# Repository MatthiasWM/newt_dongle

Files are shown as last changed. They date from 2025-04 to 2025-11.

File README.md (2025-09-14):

# User Manual
## Newton MessagePad MP2x00 and eMate 300 USB Dongle

The NewtCOM dongle connects the Apple MessagePad MP2x00 and the eMate to a PC
or Mac over USB-C.

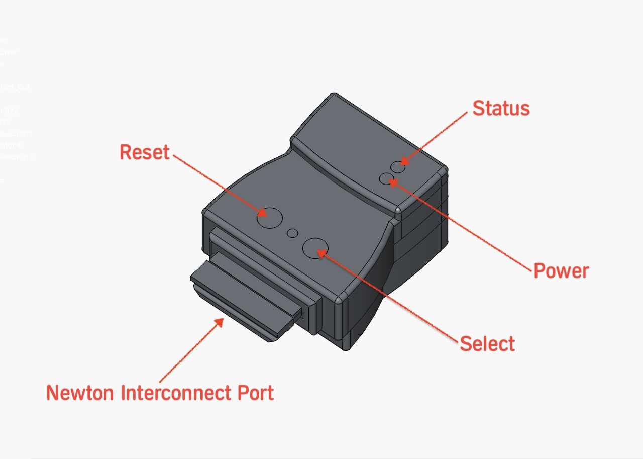
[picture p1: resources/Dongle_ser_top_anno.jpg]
Dongle Front Top View


The dongle plugs into the rear of the MessagePad or the left side of the eMate.
On the top are two recessed buttons, one for resetting the device, and a second
button to select additional functions.

Two LEDs indicate the current state. The Power LED lights up red when the 
Dongle is either connected to a USB-C port, or when plugged into the Newton
*and* a serial connection is requested.

The Status LED shows the communication status of the Dongle.

 - yellow: idle, waiting for a connection
 - green: an application on the PC or Mac has connected to the Dongle over USB-C
 - blue: the Newton is connected to the Dongle's built-in NCU
 - flashing light blue: the Dongle is reading from the SD Card

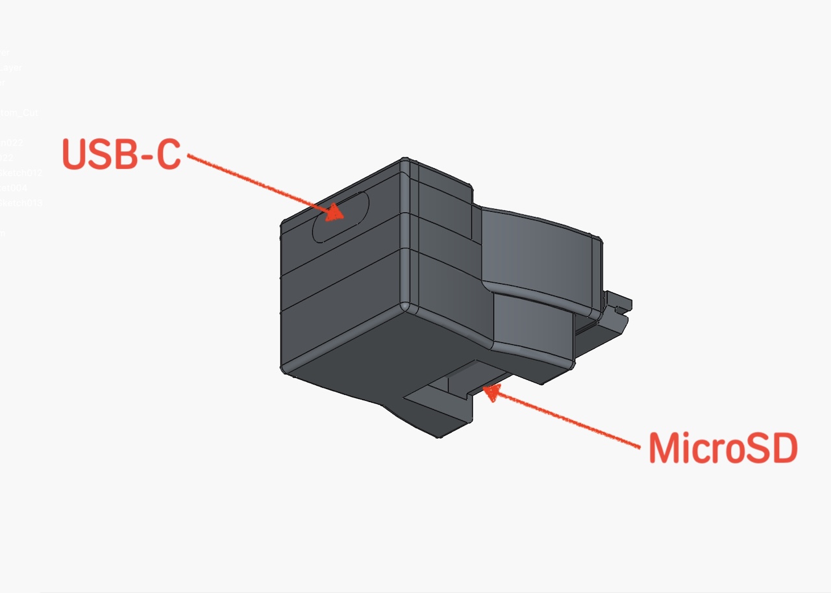
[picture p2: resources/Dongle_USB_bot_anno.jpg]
Dongle Back Bottom View


### USB-C Port for Data and Power

The USB-C port is located on the back of the dongle. When connected to a PC, it 
typically supplies enough power to operate the Newton with two standard PCMCIA 
cards installed.

However, this may not be sufficient to power WiFi cards or charge the battery pack.

### MicroSD Card Slot

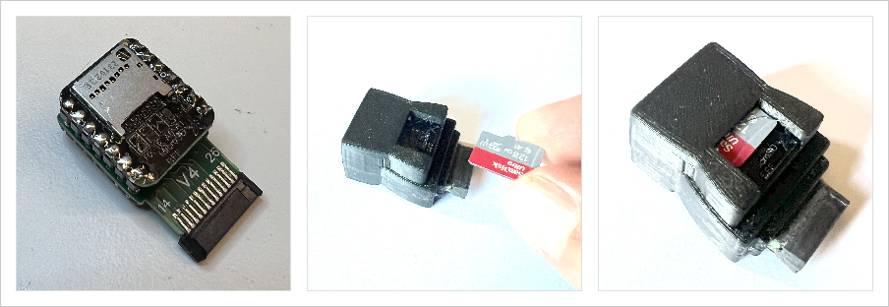
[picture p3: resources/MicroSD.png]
Micro SD Card Slot


The bottom of the dongle includes a slot for a MicroSD card. To insert or 
remove the card, you must first unplug the dongle from the MessagePad.

When inserting the MicroSD card, make sure the metal contacts face the 
dongle — this is the "up" direction when the dongle is connected to the Newton.

The MicroSD card must be formatted with the FAT32 file system.

> [!TIP]
> The shape of the dongle ensures that it can't be plugged in up-side down.
> Make sure that the interconnect plug is pushed in all the way in for a secure
> connection.

## Serial Mode

The dongle works as a serial connection between the Newton and the PC or Mac,
running any of the common Newton synchronization tools. It has been tested with
NCU, NCX, unixnpi, and NTK. 

Also the low level debugging tool Hammer works fine using the BasiliskII emulator.
Note that older versions of Baslilisk do not support serial port emulation.
These versions should: 
[MacOS](http://messagepad.org/Downloads/Einstein/MacOS/BasiliskII.MacOS,E.2.zip),
[Windows](http://messagepad.org/Downloads/Einstein/MSWindows/BasiliskII.Windows.E.4.zip),
[Linux Ubuntu LTS](https://github.com/pguyot/Einstein/releases/download/v2022.4.17/Einstein_linux_x64_fltk_v2022.4.17.zip).

### USB-C Serial Connection

When the dongle is connected to a modern computer via USB-C, it appears 
as a serial port.

 - On macOS and Linux, it will show up as something like 
   `/dev/cu.usbmodem83201` (the exact number may vary).
 - On Windows, look for a COM port such as `\\.\COM5` or similar in your 
   device manager.

###  Transfer Speed

The communication speed is controlled by the computer. For example, NCX can be 
set to use a faster transfer rate like 115,200 bps instead of the default 
38,400 bps. If you choose a higher speed, be sure the "Serial 11200" Dock 
package is installed on the Newton.

The dongle automatically adjusts to the speed set by the computer. If no 
computer is connected, it defaults to 38,400 bps.

### Flow Control

The NewtCOM dongle uses Newton-style hardware handshaking and includes 
internal throttling to ensure smooth, reliable data transfer.

> [!TIP]
> If transfer of large files still occasionally hangs during transfer, the 
> throttling parameters can be adapted using Hayes commands (see below). 
> The default values are an educated guess. Please let me know if you find
> better values that work for every configuration.

## Dock mode (Firmware v0.6 and later)

Firmware version 0.6 introduces basic support for the Newton Docking protocol. 
This allows the dongle to emulate a minimal NCU-like app, enabling package 
installation directly from a MicroSD card—no computer required.

### Preparing the MicroSD Card

 - Copy your .pkg files to the MicroSD card.
 - You can organize them into folders; subfolders are fully supported.
 - For best performance, limit each directory to no more than 50 files or folders.
 - The card must be formatted as FAT32.

### Using Dock Mode

 - Insert the MicroSD card into the slot on the bottom of the dongle.
 - Connect the dongle to your Newton. (It can also be connected to a computer 
   via USB, but no app like NCX or NCU should be actively using the port.)
 - The LED on the dongle should light up yellow, indicating it's ready.
 - On your Newton, open the Dock app.
 - Select `Serial` as the connection method, effectively setting the speed to 38,400 bps.
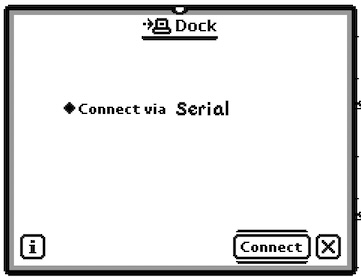
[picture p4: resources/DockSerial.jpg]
Dock Serial
   
 - Tap Connect. After 4–5 seconds, the LED will change to blue, and a Docking 
   window should appear with an option to browse the SD card.
 - Tap the icon to view a list of files and folders.
 - Select a package, tap Install, and the Newton will download and install 
   it directly from the card.

> [!TIP]
> If no SD Card is in the slot, or NewtCOM can't read the SD Card for some
> other reason, the name of the card will be "Error". Try to reset the dongle.
> If that does not help, remove power from the dongle and start over. If that
> still doesn't help, try another SD Card.

## Updating Firmware

All official releases of the firmware will be published [here](https://github.com/MatthiasWM/newt_dongle/releases).

To update the firmware, download the file ending in `.uf2` to your PC. 

To put the dongle into firmware mode:

- disconnect the dongle from the Newton
- connect the dongle to your PC or Mac via USB-C 
- get two pointy tools to press the recessed buttons
- press and hold the RESET button
- press and hold the SELECT button
- release the RESET button
- release the SELECT button
- the dongle switches into firmware mode and shows up as a new USB drive `RPI-RP2` on your desktop
- now simply drag and drop the `.uf2` file onto the USB drive
- the USB drive will disappear and the dongle will reboot into the new firmware

## Hayes Command Mode

The NewtCOM dongle can be put into Hayes command mode on both the serial port 
and the USB port. To do this, you will need a terminal program. On the Newton
side, this is commonly `PT100`. The Newton serial port speed defaults to 38'400bps. 

There are many VT100 or simpler terminal programs for PCs 
and Macs. The dongle should be listed as `/dev/usbmodemXXX` where XXX is 
some random number. If connected via USB-C, the dongle will adapt to the serial port
speed set by the PC.

To get into Hayes mode, don't send any data for at least one second. 
Then, again within a second, type `+++` (three plus characters - on PT100, you can
create a macro for that - don't press Return). After yet another second 
without, if no keys are pressed, the dongle will reply with `OK`. 

You are now in Hayes mode. To get back online, type `ATO` (the letter "O", 
like Online). The dongle replies `CONNECT` and leaves Hayes mode.

There are few Hayes commands at this point, but there will be more:

- `ATO` : go back online
- `ATIn` : get information about the firmware and the firmware version number, n can be 0, 1, or 2.
- `AT&W` : write current settings to Flash memory
- `ATS12=n` : set the Escape Code guard time in n times 1/50th of a second (defaults to 50)
- `ATS300=n` : set the MNP throttle delay to n microseconds (defaults to 400)
- `ATS301=n` : set an additional delay in number of characters (defaults to 8)
- `AT[GL` : get the SD Card label

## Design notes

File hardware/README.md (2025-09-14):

# Hardware supported by NewtCOM firmware

As of May 2025, `NewtCOM` supports  the RP2040 base NewtCOM Dongle. 

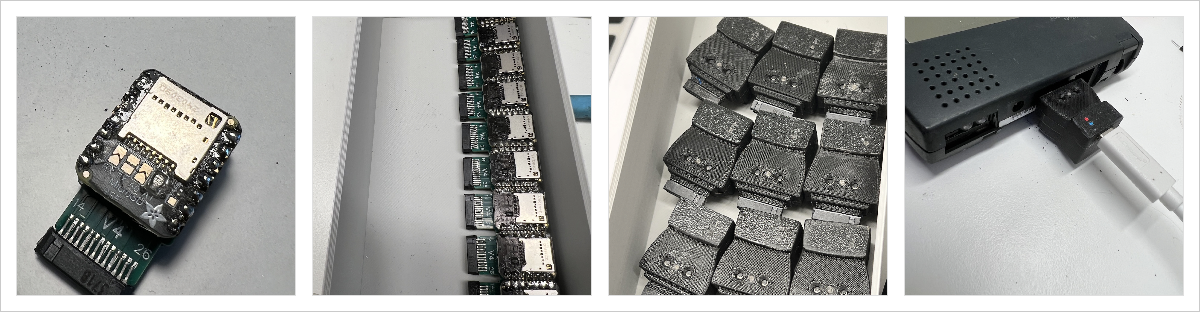
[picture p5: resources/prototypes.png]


## The NewtCOM Dongle

The design of the dongle is OpenSource and I encourage anyone with sufficient 
soldering skills to build their own dongle. There is a base dongle that 
converts the Serial Port signals on the Interconnect port to USB-C. Optionally,
the dongle can convert the 5V form the USB-C to 7V to run the Newton. There
is also an option for a MicroSD card slot for installing software without
needing a PC, and eventually for making backups and restoring the content of 
the MessagePad or eMate.

So here is how you build one:

Parts:

- Interconnect Port connector 
  - V4: Molex 71439-0964, Mouser: 538-71439-0964
  - V5: Molex 71439-1464, Mouser: [538-71439-1464](https://www.mouser.de/ProductDetail/Molex/71439-1464)
- RS422 circuit board ([oshwlab.com](https://oshwlab.com/matthiasm/interconnecttousb_copy_copy_copy))
- XIAO RP2040 circuit board, [Seeed Studio](https://wiki.seeedstudio.com/XIAO-RP2040/)
- optional: Pololu 4943 DC-DC power converter, [Pololu](https://www.pololu.com/product/4943)
- optional: Adafruit 5683 microSD Card BFF, [Adafruit](https://www.adafruit.com/product/5683)
- various pin headers that usually come with the boards above
- 3d printed case (TODO: insert link)

Tools:

- Soldering iron and solder wire
- Hot air gun and SMD solder paste
- multimeter
- small needle nose pliers
- small hacksaw
- electronics wire cutter
- 3d printed jigs

## Step by step

### Ordering the RS422 circuit board

The PCB design can be dowloaded for [oshwlab.com](https://oshwlab.com/matthiasm/interconnecttousb_copy_copy_copy). The PCB can be manufactured based on these
files. Some services (I used JLCPCB) offer the complete assembly for a low rate
if you can't solder SMDs, especially the tiny diode.

The PCB should be 1.6mm thick.

### Preparing the Interconnect Port connector

#### IEEE 1386

The original Interconnect Port connector is no longer manufactured. We are 
helping ourselves with a heavily modified IEEE 1386 connector. One Molex 
71439-0964 (Mouser 538-71439-0964) yields two Newton connectors.

V5 and up uses 71439-1464.

Note that after cutting these to pieces, they wil not be as strong as the 
originals, and I have not found a way to cut the shielding. For normal use, this
should not matter.

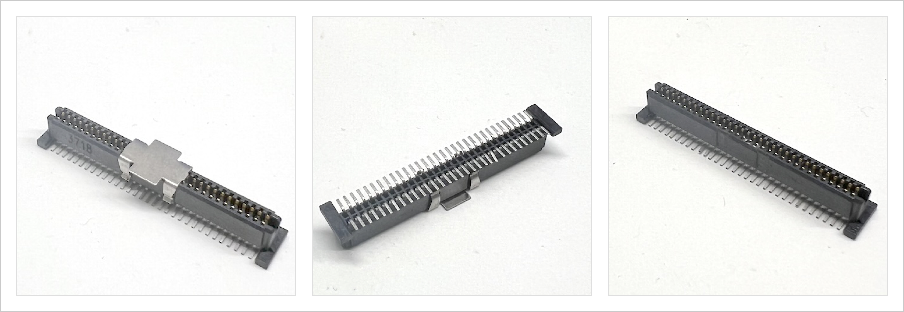
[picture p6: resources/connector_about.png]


This is the standard Molex IEEE 1386 connector. Remove the metal cap (that's
only needed for pick'n'place machines) and make sure the pins on the bottom are not bent out of shape.

#### Jigs

After cutting and filing a few connectors by hand, I decided to build jigs that make this work really easy. The STL files to print the jigs are [here](/3d-parts/jigs/). I printed the jigs with a 0.4mm nozzle at 0.2mm layer height.

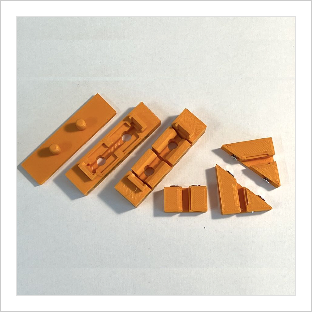
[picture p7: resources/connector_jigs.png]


#### Prebend

We need to remove 12 pins from the connector. Our (Prebend Jig)[/3d-parts/jigs/Connector_Prebend_Jig.stl] bends those pins that must be removed. Just push the connector all the way into the opening. Use the ejector to remove the connector again.

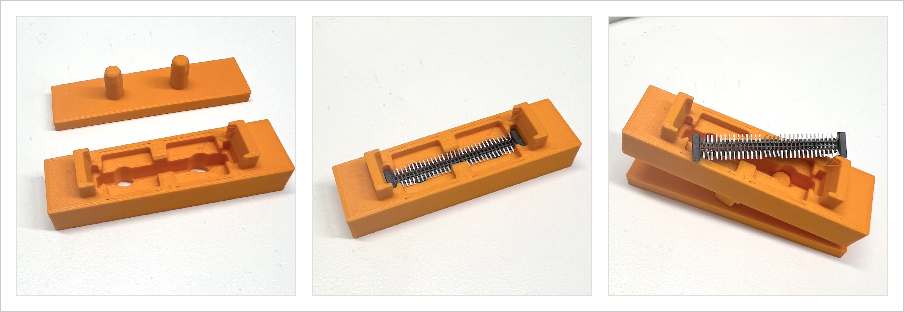
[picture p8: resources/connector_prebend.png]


The jig will bend the pins that need to be remove up slightly. Take your needle nose pliers out and remove the first pin, the four center pins, and the last pin on each side, so 12 pins alltogether. We should have two groups
of pins now on either side with 13 pins per row, or 26 pins per group.

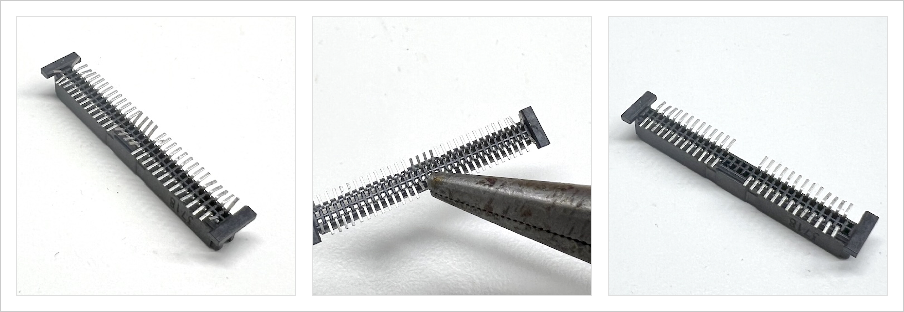
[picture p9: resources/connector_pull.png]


#### Cut

Use the cutting jig and the small hacksaw to cut the original connector into two new connectors. Three cuts are needed.

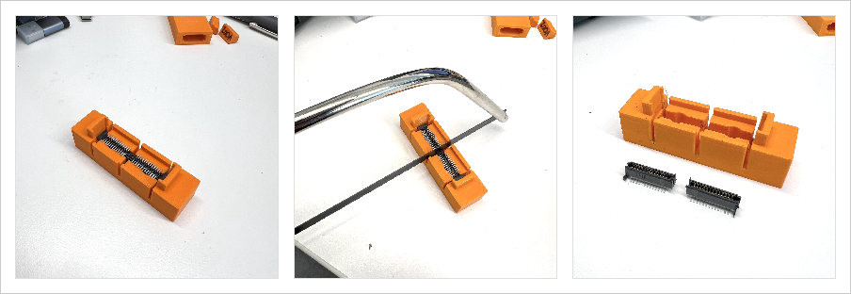
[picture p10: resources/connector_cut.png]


#### File Sides

The Interconnect Port connector must be 15.6mm wide. File the plastic off of our part evenly on both ends until you reach the desired width. The jig can help, but the 3mm bolts must be adjusted to the correct distance.

*Don't* bend any pins.

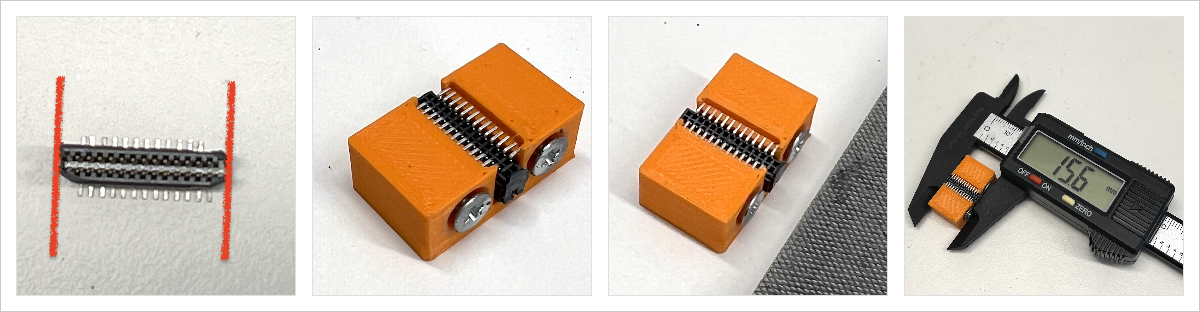
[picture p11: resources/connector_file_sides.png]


#### Final Bend

This step is the most difficult one. The connectors tend to break if done 
incorrectly. So I developed a jig that makes this step much easier. 

Insert the plug into the top of the bender. Insert the plunger between the pin 
rows and push it all the way down.

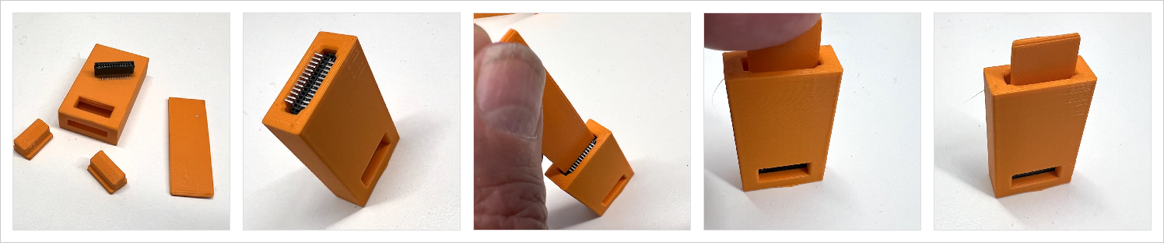
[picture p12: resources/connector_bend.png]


Keep the plunger between the contacts and grab the two pistons. Without 
lifting the jig, push the two pistons into the side openings (the slant 
faces down). Remove the plug. The pins are now bent away from the plug without 
damaging the plug's case. 

With the pins bent to back, we can now file the indexing corners.

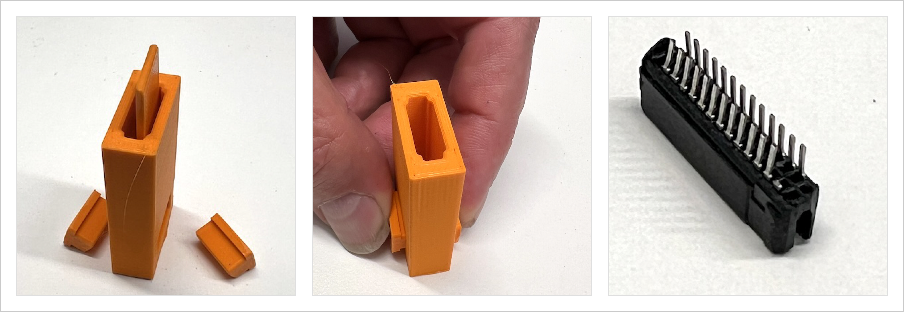
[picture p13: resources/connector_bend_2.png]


#### File Corners

To ensure that the connector is not inserted upside down, the corners on the 
bottom must be filed to 45 degrees. Again, the two jigs for left and right 
should help. Make sure that you file the corners on the *same* side.

*Don't* bend any pins.

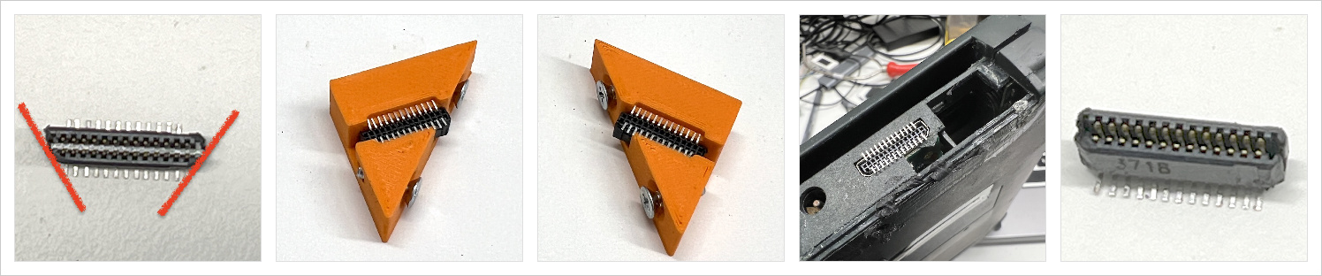
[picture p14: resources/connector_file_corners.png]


The last image show a test fit in a MessagePad. The connector should fit snug, 
but not get stuck. Did I mention to not bend any pins? Well, if you did, and 
you did bend them back too many times, they probably broke off by now. Throw 
away the connector and try again.. 

### Soldering the connector

Position the connector correctly on the RS422 board. The first two images show the *bottom* of the board. Make sure that the 45 degree corners are on the *bottom* side of the PCB. The third image show the *top* of the PCB with no parts on it. The connector must have the 90 degree corners on the top!

Look at the PCB from the side: the connector must be straight with the PCB, not pointing up or down.

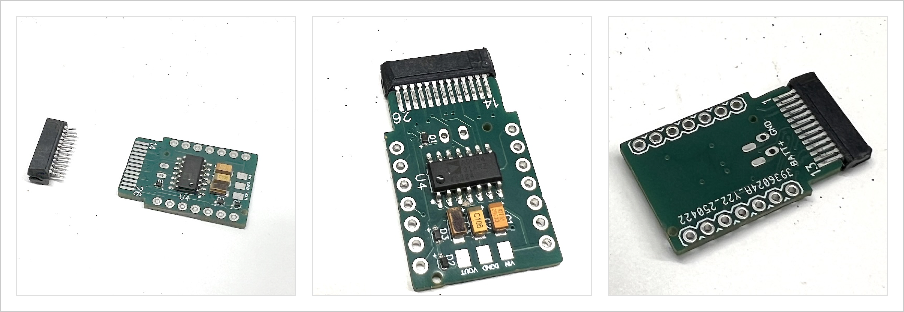
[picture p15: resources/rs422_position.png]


Soldering is easy with some fresh solder paste and a hot air gun. Just add a small bead and heat one side of the connector until the solder balls disappear and teh solder is shiny. The pin distance it 1mm. It's also relatively easy to solder this with a regular soldering iron, flux, and a fine tip.

Did you solder the connector on the right way? Did you make sure the 45 degree corners are on the side where the parts are?

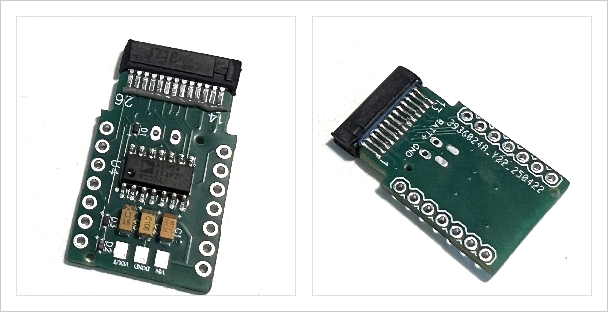
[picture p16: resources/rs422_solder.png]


Let's do a mechanical check first. Here we see the RS422 board plugged into my MessagePad (it's a very roughly used MP, sorry for the scratches). The left photo show the top view, the right photo is taken from the bottom.

If you are unsure about your soldering, use a multimeter to check for shorts between pins.  Pin 15 and 16 are connected and will show a short circuot correctly. The remaining neighbors should show a high resistance.

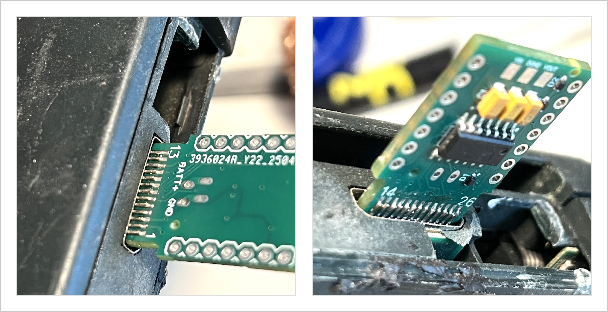
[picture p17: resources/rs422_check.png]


### Adding the DC-DC converter

The DC/DC converter takes power from the USB-C port, raises the voltage to 7.5V,
and then powers the Newton through two diodes and a filter. 

In the following pictures, I soldered the CPU board first, but it's better to 
add the DC/DC module first, so here we go:

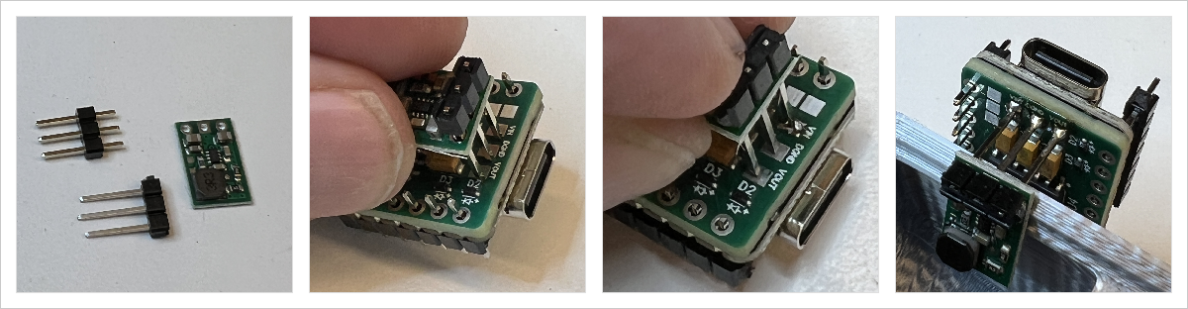
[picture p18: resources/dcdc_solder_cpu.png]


Prepare a three-pin pin header by pushing the plastic all the way up.

Put the DC/DC inverter module on the pin header. This will help keeping the
pins aligned later.

Put a first solder blob on the PCB and fix the first pin. 

When everything is aligned well, solder the other two pins onto the PCB.

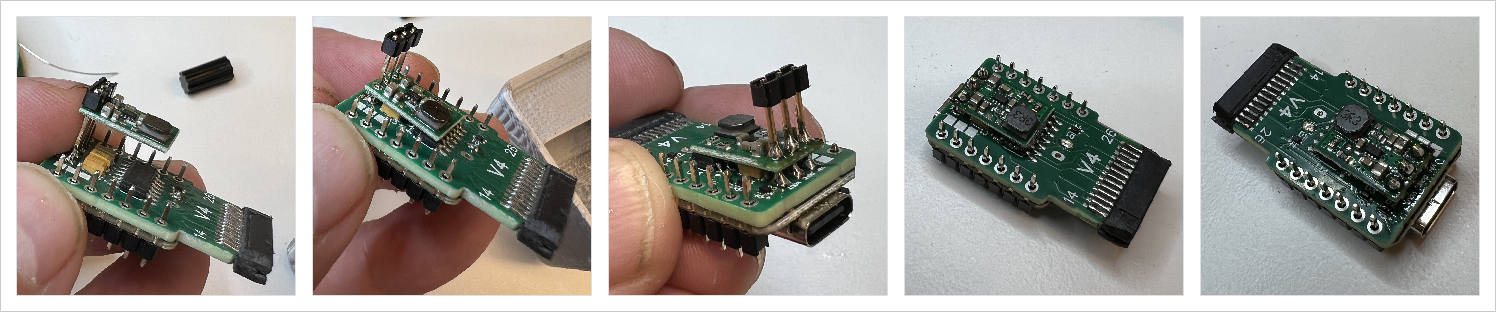
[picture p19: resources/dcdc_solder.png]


Slide the DC/DC board down and attach it to the capacitors below with a bit
of glue. This will take load off of the power pads.

Solder the three pins to the module, the remove the plastic - be careful to
hold the DC/DC module when pulling, so you don't rip the pads form the 
RS422 PCB! Finally, but the pins, and the DC/DC module will fit nicely between
the RS422 and the MicroSD board.
 
### Soldering the RS422 board to the RP2040 board

Next we will solder the CPU board to the RS422 board. Note that in the description,
I soldered the DC/DC board first, which is preferred. The photos still show
the old method. 

For now, there is only one single pad that can be soldered. The remaining pins 
will be soldered later. If connected correctly, the Newton Batt+ pin will power 
VIN on the dongle if there is no PC connected. 

From now on, the connected boards must be 
handled very carefully, or the 5V pad will delaminate.

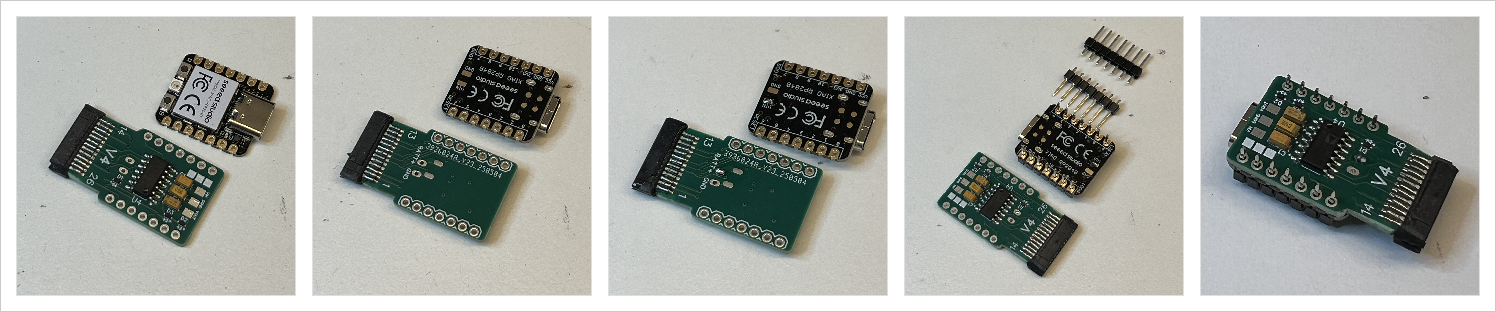
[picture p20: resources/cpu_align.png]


Prepare the CPU board by adding a little solder blob on the `VIN` pin. Put another
small blob on the underside of the RS422 board on the `BATT+` pin. 

Align the boards back to back using the pin header.

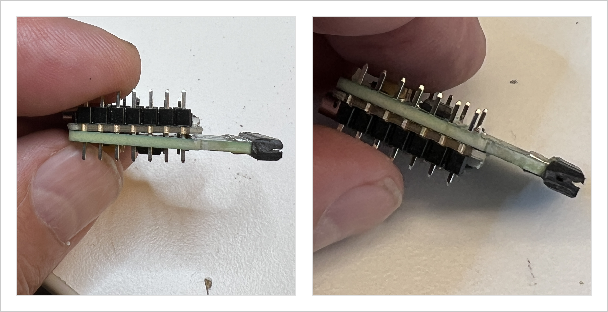
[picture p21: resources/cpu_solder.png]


There is a gap visible from the sides where both solder ball touch, but have
not melted together yet. Place the dongle firmly on the table with the CPU
board at the bottom and the RS244 board at the top. Hold the soldering tip 
to the `BATT+` through-hole, and after a second or so, both solder blobs will 
melt, joining the boards permanently. 

The gap is no longer there, and both boards stick together. 

### Adding the MicroSD board

Prepare the MicroSD board for the dongle by reconfiguring the solder pads. 

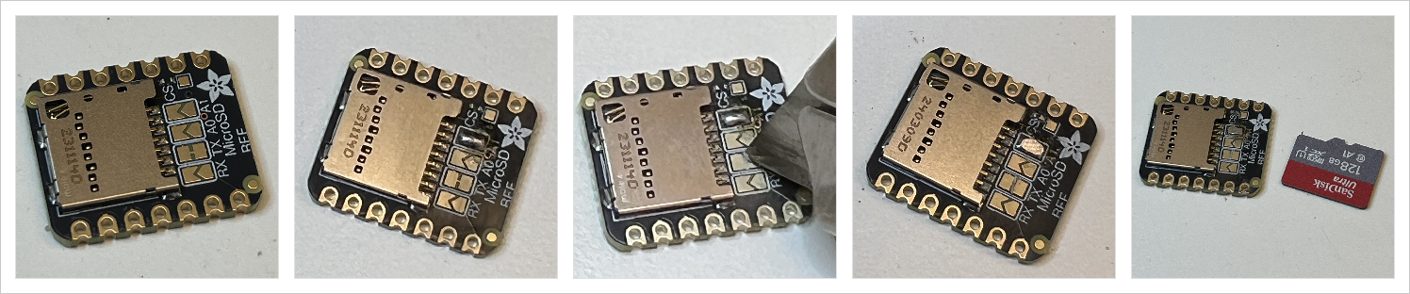
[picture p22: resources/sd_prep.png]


The SD Card module is preconfigured to select the card using the `TX` pin. We will
need the `TX` pin to send serial data to the Newton, so instead we use `A1`.

Put a solder blob on the `A1` pads so that both sides connect. File the resulting
blob down enough, so the SD Card can slide over it. Don't accidentally file the 
contacts on the sides though.

Cut the small wire between the pads of the `TX` pin with a knife. Make sure that 
there is a wide enough gap. 

It's a convinient time no to use black marker to make the color match
the dongle case.  

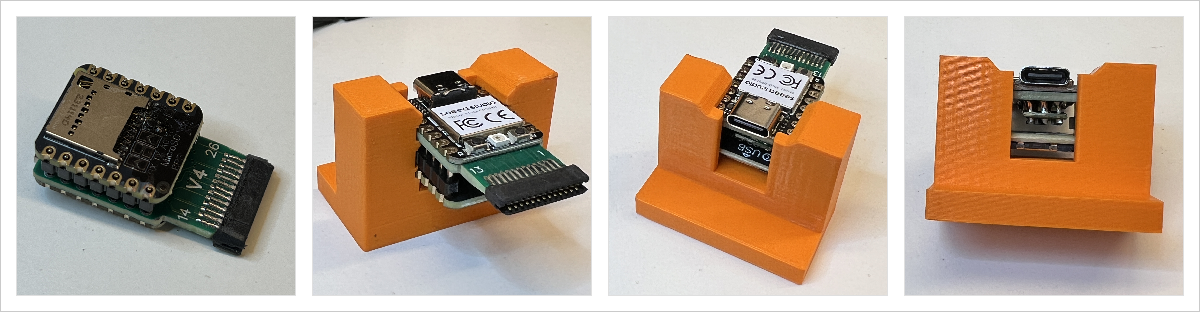
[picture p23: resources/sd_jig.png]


Without putting any stress on the CPU/RS422 sandwich, flip the header pins
in the final direction.

Add the MicroSD module to our package. Make sure that the board is oriented
in the correct way. After all the work to get here, you really don;t want to
find out that the SD Card points the wrong way when zou put everything in
the case. Ask me how I know... .

Get the assembly jig. It will make sure that the PCBs hav the right distance 
and will fit into the case later. Push the PCBs all the way to the front.
Lift the headers so the plastic fits into the gap. The tips of the pins will be 
flush or barely show, but should not be retracted, or the soldering connection will not work. 

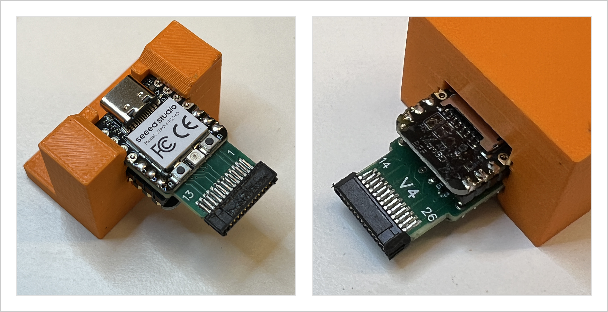
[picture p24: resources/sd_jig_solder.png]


Is the MicroSD module oriented correctly?

While the module is still in the jig, solder the six visible pins on the top
and of the bottom of the module. The PCBs are now permanently aligned. Remove
the module from the jig..

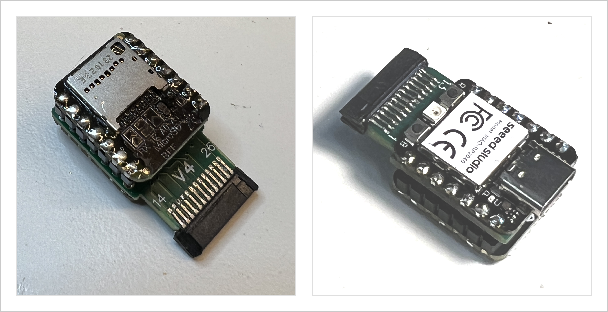
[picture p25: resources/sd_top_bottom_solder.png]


Solder the remaining pins on the top and bottom of the module. Look again.
Didi you really solder *all* of them?

* Pictures missing *

Note that the sandwiched CPU/RS422 boards don;t always connect all the way 
through. Use the angled jigs to solder the pinheaders from the RS422 side of 
the module as well.

### Flashing the Firmware

TODO: write me!
- USB Drive mode
- drag and drop

### Testing the dongle

TODO: write me!
- test power from interconnect port
- test power from USB-C
- test power to Newton
- Hayes mode, AT commands
- practical tests: NCX, Basilisk and NCU
- practical test SD Card

### Putting everything in a case

TODO: write me!
- choose a case
- print the case
- glue

### Adding the light pipes

The CPU module has three LEDs that are hard to see when the boards are 
in the case. This is easily fixable by adding light pipes, 1.5mm fibers that
illuminate the end points (there are others available that illuminate the 
circumference - don't use those).

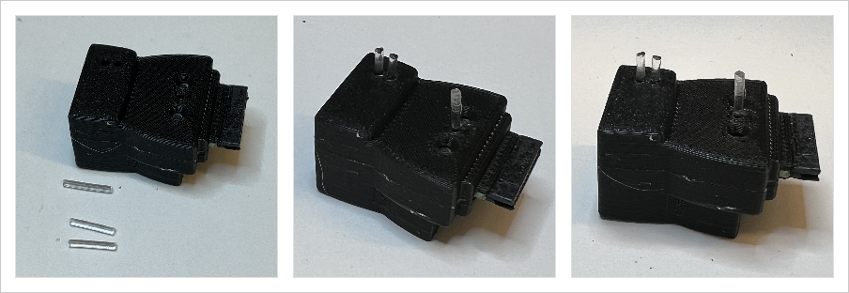
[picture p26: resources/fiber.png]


Use a drill to expand the holes of the 3d printed case to 1.5mm. Cut 
10mm pieces of fiber from the roll. Add some liquid plastic glue and push 
the three pieces int the holes. The State and Power light holes are a few
mm deep, but the front RGB LED hole is quite shallow, but since that LED
is hidden by the MP2x00 lid, it's of no use anyway.

Wait a few minutes for the glue to set, then cut the fibers with a side cutter.
There is no need to file to ends of the fiber. It;s a status LED< not an 
internet backbone connection between continents.

### Done

So, that's it from my side. You should have a nice and working dongle now.
Enjoy the Newton!

Matthias

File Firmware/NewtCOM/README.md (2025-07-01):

```
// SPDX-License-Identifier: MIT
// Copyright (c) 2025 Matthias Melcher, robowerk.de
```

# NewtCOM Dongle configuration

This is the build configuration for running the NewtCOM firmware on a 
NewtCOM Dongle with an RP2040 CPU. The firmware installes to Flash memory.

Parallel to this configuration is the PiPico setup for compiling the 
same firmware for the PiPico developer board.

## My TODO List for NewtCOM Dongle

see: [../PiPico/README.txt](../PiPico/README.txt)

Also:
 - [ ] User Documentation, reference to the resources that we use

 ## Hardware

 The pack is built with 10.5mm long pin headers, giving a top-bottom distance
 of 9.1 to 9.5mm. The overall hight is 12.5mm without USB and 13.9mm with USB
 connector. 
 
 Tip of the plug to front edge of PCBs is 10.4mm. Length over all is 31mm and
 32.5mm including the USB port.

 Width is 17.8mm. 

 The original dongle is 21.4 to 24.7mm wide, 20mm tall, and 39.4mm long 
 with Interconnect and 32,4mm without.

## Staus Report

The dongle can pipe data from the serial port to the USB port and back reliably at 115200. Various test were done with NCX and BasiliskII and 
Inspector.

The Dock protocol is implemented well enough so the Newton can establish
a connection to an emulated NCU, browse files and directories on the 
SDCard, and download and install them.

## GitHub

Task to build PiPico stuff on GitHub:

https://github.com/raspberrypi/pico-examples/blob/master/.github/workflows/macOS.yml

To drop **7.5V to \~7.2V** using two **series diodes**, you're doing a very common trick — using the **forward voltage drop** of the diodes (\~0.3V total) to bring the voltage into spec. Let’s walk through the choices and protection details.

---

### 🔧 Diode Selection

Since you're passing **up to 1A** of current, you need:

* A diode with **low forward voltage** (typically 0.2–0.4V).
* A diode that can handle **at least 1A continuous current**.
* A **common SMD package** for ease of assembly.

#### ✅ Recommended SMD Diodes

| Diode | Type | Package | Vf @ 1A | Max I | Notes |
| --- | --- | --- | --- | --- | --- |
| **SS14** | Schottky | SMA | \~0.4V | 1A (Avg) / 30A (surge) | Very common, cheap, ideal for power rails |
| **SS34** | Schottky | DO-214AB (SMA/SMB) | \~0.4V | 3A | More margin, same voltage drop |
| **MBRS130L** | Schottky | SMB | \~0.3V | 1A | Lower Vf than SS14, also common |
| **BAT54C** | Dual Schottky | SOT-23 | \~0.3V @ lower current | 200mA per diode | Too small for 1A total |

For your case:
👉 **Use two SS14s or MBRS130Ls in series**.
They’re widely available, cheap, and reliable.

---

### ⚠️ Do You Need a Fuse?

Yes, **some form of protection is wise**. DC-DC converters can fail shorted or supply too much current in a fault scenario. You want to prevent overheating or damage.

#### 🔌 Options for Electronic "Fusing":

1. **Resettable Polyfuse (PTC)**

   * Simple, self-resetting.
   * Choose one rated for **1.1–1.5A hold**.
   * Example: **MF-MSMF110** (1.1A hold, 2.2A trip).
   * SMD versions available.

2. **SMD Fuse (non-resettable)**

   * More compact and predictable.
   * Choose \~1.5A fuse to protect the 1A line.
   * Littelfuse 045101.5MRL (1206, 1.5A).

3. **Electronic Fuse IC**

   * Active current limiter (e.g., TPS25940 or similar).
   * Overkill unless you're designing for high reliability.

For most DIY or low-volume boards:
👉 **A polyfuse + TVS diode** offers good balance between protection and simplicity.

---

### 🛡️ Bonus: Add a TVS Diode for Transients

Put a **TVS diode** on the 7.2V output to clamp voltage spikes.

* For 7.2V nominal, use something like **SMBJ8.0A** (clamps at \~13V, starts at 8.9V).
* Pick one based on how sensitive your load is.

---

### ✅ Summary

* **Use 2x SS14 or MBRS130L diodes in series** to drop 0.3V.
* **Add a resettable fuse** (1.1–1.5A) or SMD fuse on the 7.5V or 7.2V line.
* **Optional but recommended:** TVS diode to protect from spikes.

Let me know what your load is — I can help tune the exact diode and protection setup.

Thanks — the Apple **Newton** is indeed **very sensitive to overvoltage**, especially on the external power input, as it was designed around linear regulators and NiCd/NiMH charging circuits. Given that:

---

### 🚨 Key Constraints

* **Never exceed 7.3V** (absolute max).
* Nominal target: **7.2V ± 0.1V**.
* Current draw: typically **<100mA**, but **may spike to 1A** when charging.
* Load is **delicate**, so reliability and protection matter more than just basic functionality.

---

### ✅ Best Diode Setup

To drop 7.5V to \~7.2V:

#### Recommended diode:

* **MBRS130L (SMB)** or **1N5819-SMD**

  * Forward drop: \~0.35–0.4V at 1A, less at lower current.
  * Current rating: 1A continuous.
  * Soft turn-on, minimal overshoot.

These will each drop around **0.2–0.3V at 100mA**, or **0.35–0.4V at 1A**. Two in series should bring 7.5V down to \~7.2V or slightly below under load — **perfect** for your case.

✅ Use: **2x MBRS130L diodes in series** in the main power path.

---

### 🔐 Protection: You Absolutely Need a Fuse and Clamp

Overvoltage = instant damage to the Newton. You want **two layers of defense**:

#### 1. **Fuse or Polyfuse**

* Use a **fast-acting SMD fuse**, like:

  * **Littelfuse 0451.125MRL** – 125mA
  * **0452.500MRL** – 500mA for some charging margin
* Or a **polyfuse**, like:

  * **MF-MSMF050-2**: 0.5A hold, \~1A trip
  * **MF-MSMF075-2**: 0.75A hold, \~1.5A trip

A polyfuse is slower but self-resetting — more forgiving.

#### 2. **TVS Diode (Clamp)**

Place a **TVS diode across the Newton’s supply input**, just before it connects to the device:

* Use **SMBJ7.0A** or **SMBJ6.5A**:

  * Breakdown: \~7.0V
  * Clamps: \~11.3V (SMBJ7.0A) or \~10.5V (SMBJ6.5A)
  * Both will prevent a >7.5V surge from reaching the Newton.

> **Note:** A Zener diode is *not fast enough* for this. Use a **TVS (transient voltage suppressor)**.

---

### 🧱 Suggested Power Path Summary

```text
[USB-C 5V] ─> [Boost Converter to 7.5V] ─> [Fuse or Polyfuse]
                                               │
                                ┌──────────────┘
                          [2x Schottky Diodes (SS14 or MBRS130L)]
                                               │
                                       [TVS Diode to GND]
                                               │
                                          [Newton Input]
```

---

### ⚙️ Extra Tips

* Test under load with multimeter: the forward drop **will vary** from \~0.25V (100mA) to \~0.4V (1A).
* Make sure the **boost converter is well filtered** — Newtons are also sensitive to ripple.
* You might consider a **low-dropout linear regulator** (e.g., **MIC29300-7.5**), but diodes are easier and smaller for this use case.

---

Would you like me to suggest exact part numbers and footprints for your PCB?

Perfect — here’s a clean, **low-part-count and safe design** for powering the Apple Newton from a USB-C supply, with **all the exact SMD part numbers** and footprints you can drop into your PCB layout.

---

## 🧩 Final BOM & Footprints

### 1. **DC-DC Boost Converter (5V to 7.5V)**

* You already have this — just ensure it’s:

  * Capable of stable 7.5V out @ 1–1.5A.
  * Has low ripple (<50mV) and soft start.

---

### 2. **Fuse / Polyfuse**

#### Option A: *Resettable Polyfuse* (recommended for gentle protection)

* **Part:** [Littelfuse MF-MSMF050-2](https://www.littelfuse.com/products/resettable-ptcs/surface-mount/mf-msmf-series/mf-msmf050-2.aspx)
* **Rating:** 0.5A hold / 1A trip
* **Footprint:** 1206 (3216 metric)

#### Option B: *SMD Fuse* (faster, non-resettable)

* **Part:** [Littelfuse 0452005.MRL](https://www.littelfuse.com/products/fuses/surface-mount-fuses/pico-smd/0452/0452005.MRL.aspx)
* **Rating:** 500mA fast-blow
* **Footprint:** 1206 (3216 metric)

---

### 3. **Series Diodes (for voltage drop)**

* **Part:** [MBRS130L-TP](https://www.diodes.com/assets/Datasheets/ds13001.pdf)
* **Rating:** 1A avg, 0.35V drop at 1A
* **Footprint:** SMB (DO-214AA)

💡 You’ll use **2x in series**. Place them with current flowing **from boost converter to Newton input**.

Alternate: [SS14](https://www.onsemi.com/pdf/datasheet/ss14-d.pdf) — also works, slightly higher Vf.

---

### 4. **TVS Diode (Overvoltage Clamp)**

* **Part:** [SMBJ7.0A](https://www.littelfuse.com/products/tvs-diodes/smbj/smbj7-0a.aspx)
* **Rating:** 7.0V breakdown, clamps at \~11.3V
* **Footprint:** SMB (DO-214AA)

💡 This protects the Newton against spikes or DC/DC runaway. Connect from **7.2V rail to GND**.

Alternate (tighter clamp): **SMBJ6.5A** – breaks down at 6.5V, clamps around 10.5V, but may trip under brief surges.

---

## 🧾 PCB Layout Notes

* Place **TVS diode** physically **close to Newton input pin**.
* Route **diodes** and **fuse** in series on the high side (not ground).
* Keep all high-current paths **short and wide** (>=40 mil trace if possible).
* Add **10µF ceramic + 100nF ceramic** bypass caps at Newton input to reduce ripple and absorb switching noise.

---

## 💡 Summary

| Function | Part Number  | Package | Value/Rating |
| --- | --- | --- | --- |
| Resettable Fuse | MF-MSMF050-2 | 1206 | 0.5A hold / 1A trip  |
| Diodes (x2) | MBRS130L-TP  | SMB | 0.35V drop @ 1A each |
| TVS Clamp | SMBJ7.0A | SMB | 7.0V breakdown |

Would you like me to generate a KiCad footprint library for these parts or an example schematic layout?

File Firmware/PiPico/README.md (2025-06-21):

```
// SPDX-License-Identifier: MIT
// Copyright (c) 2025 Matthias Melcher, robowerk.de
```

# PiPico configuration

This is the build configuration for running the NewtCOM firmware on a 
PiPico developer card with an RP2040 CPU. The firmware installes to RAM
for speed and to avoid Flash use.

Parallel to this configuration is the NewtCOM setup for compiling the 
same firmware directly for the RP2040 based dongle.

## My TODO List for PiPico

 - [x] Check if the current Workspace compiles and debugs on our current hardware
 - [x] Change install type to RAM
 - [x] Implement the base classes in `common/`
 - [x] Implement the derived classes for the Pico
 - [x] Implement pipes for data and control
 - [x] Get a minimal serial port forwader running
 - [x] Test the serial port forwarder
 - [x] Implement data vs. command mode and a few AT commands in `common`
 - [x] Implement a DELAY event (absolute time, number of bytes, flush FIFO)
 - [x] Implement a MNP scanner that can insert delays after a block is received
 - [x] Test with script
 - [x] Clean up Workspace
 - [ ] Rename `send()` to `relay()` to make it clearer what the function does?
 - [x] UserInterface class to control LEDs and listen to buttons
 - [ ] Optional firmware to reset Flash memory? Or any other way to reset it?
 - [x] MNP Filter that extracts Dock commands and data (takes care of 
       negotiation, blocks, replies, checksums, resends)
 - [x] Switching pipe between Dock and CDC based on CDC DTR signal
 - [x] Dock, a filter that understands and handles Newton Dock commands
    - [x] Rough first implementation
    - [x] Functional Reset for multiple connections
    - [x] Browse and donload packages from SD Card
    - [ ] Full Error handling an documentation
 - [ ] Async class for all things that take more time than we have in a slice
    - [x] Async log: logging via debugging serial port or to SD Card
    - [ ] Async SD Card data and directory reading
 - [ ] Fill in missing documentation
 - [ ] Pipe could be able to handle block data in addition streaming data
 - [ ] Verify that we actually run on a PiPico, and not a NewtCOM dongle

 ## Notes

 - In `CMakeLists.txt`, we set `pico_set_binary_type(newt_dongle no_flash)`.
   This is to keep wear on the Flash low and to make debugging iterations fast.
 - Do we need to apply for a USB Vendor ID: https://github.com/raspberrypi/usb-pid ?
 - Change USB Port name: https://sourcevu.sysprogs.com/rp2040/picosdk/files/src/rp2_common/pico_stdio_usb/stdio_usb_descriptors.c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

## Hardware

The Developer Board is built around a PiPico board on a Breadboard with flying 
wires/ It features the Newton port and inverter, the SDCard socket, and the 
RGB LED of the XIAO board. The second LED is not supported. The BOOT button
is missing, and we don't care about the DC/DC inverter here.

## Staus Report

The dongle can pipe data from the serial port to the USB port and back reliably
at 115200. Various test were done with NCX and BasiliskII and Inspector.

The DOck is implemented in a very rough way, but does allow browsing of the 
SDCard and installing ppackages.

### Timing

All devices are handles in a loop. The Newton typically communicates at 
38'400bps, but also allows 57.6, 115.2, and even 230.4kbps. The main loop
must handle at least 4'000, and at a maximum 24'000 characters per second.

The RP2040 uart supports a 32 bytes rx and tx fifo buffer. To avoid overflow,
the FIFO must be handled 125 to 750 times a second, or every 8000 or 1300 
microseconds. In the current implementation, I measured a maximum of 13 
microseconds in the CDC endpoint and 15 usec in the entire wheel.

Note however that writing to stdout messes this up tremendously and makes
the dongle lose data.

Talking about lost data. Even with HSKI and HSKO implemented, we still run out
of sync on larger files and screen dumps. I need code that triggers this
error reliably and more code to insert delays into the data transfer. 

### The Chirp

At a few points in the documentation, it was mentioned that the Newton
sends out "chirps" to let devices know that they are connected. These
chirps are a frequency sent out on HSKO when for example Dock is started.
Maybe we can use this for something?

### Pipes

(move this chapter elsewhere)

This is a firmware for a microcontroller that connects an Apple Newton 
MessagePad (MP2x00, eMate300) to the modern outside world over USB-C.
Wifi and Bluetooth are planned, but not implemented yet.

This code sees devices like the serial port and USB es Endpoints. An endpoint
can send Events to another enpoint using Pipes. Pipes generally unidirectional.
Connecting two endpoints will usually require two pipelines, one in each 
direction.

Pipe::send() will pass Events from the sending Endpoint's output to the 
reciving Endpoint. The reciver will either handel the event and return OK, 
or reject the event, expecting the sender to send the same event again in a 
later cycle of the scheduler. These events may be buffered along the way,
but will always stay in order.

Endpoints can bypass buffers in the pipeline using Pipe::rush() and will
immediatly receive an reply to the event. This will change the order of
events.

Lastly, pipes can send events up the pipe using Pipe::rush_back(). This is 
currently used by a receiving endpoint to give the sender hints for serial
port handshaking when buffers run full.

Pipes can have additional functionality. They can buffer events, or split
events into two streams which is great for logging traffic. Pipes can filter
events and add new events. The MNP Throttle looks for specifc sequences and
adds delays in the line to give the receive time to recover.

More complex filters can combine and upstream and a downstream pipe. The Hayes
interpreter is such a device. It understands Hayes 'AT' commands and can
reroute data as needed.

ChatgPT Name Ideas:

Here are some name suggestions for your Newton connector project, balancing retro charm, modern utility, and uniqueness:

---

### 🔌 **Retro-inspired + Functional**

1. **NewtonLink** – Clean, modern, sounds official.
2. **NewtBridge** – Emphasizes bridging old and new.
3. **NewtPort** – Evokes both serial/USB ports and "support".
4. **Connecton** – A twist on "Connection" + Newton.
5. **NewtNode** – Feels modern and networky.

---

### 🧠 **Quirky & Nostalgic**

1. **The Dongle** – A cheeky nod to Apple’s own term.
2. **NewtDongle** – Literal and fun.
3. **AppleCore** – A deep pun: core of Apple + computing.
4. **MessageBridge** – Homage to the Newton MessagePad.
5. **Gravitas** – The codename of the original Newton dongle.

---

### 🚀 **Modern & Techy**

1. **NewtonSyncer** – Self-descriptive and familiar.
2. **NewtFlash** – Hints at both speed and internal storage.
3. **RetroLink-C** – Adds USB-C flair.
4. **LegacyBridge** – Sums up its purpose clearly.
5. **PDA2USB** – A bit utilitarian, but SEO-friendly.

---

### 🧩 **Names with layered meaning**

1. **ArkPad** – A vessel to carry legacy data into the future.
2. **Newtonian** – Sounds techy, plays off Isaac Newton.
3. **TimeDongle** – Nostalgic, portable, like a time capsule.
4. **NewtCradle** – Evokes sync cradles from the 90s.
5. **CoreLink** – Hints at depth, legacy, and modern connection.

---

Would you like:

* Names available as `.com` domains?
* Logo ideas for the top picks?
* A poll to narrow down tone (playful, pro, nostalgic, etc.)?

Let me know your preferences and I can refine!

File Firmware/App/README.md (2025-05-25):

```
// SPDX-License-Identifier: MIT
// Copyright (c) 2025 Matthias Melcher, robowerk.de
```

# PiPico configuration

This is the build configuration for running the NewtCOM firmware on a 
PiPico developer card with an RP2040 CPU. The firmware installes to RAM
for speed and to avoid Flash use.

Parallel to this configuration is the NewtCOM setup for compiling the 
same firmware directly for the RP2040 based dongle.

## My TODO List for PiPico

 - [x] Check if the current Workspace compiles and debugs on our current hardware
 - [x] Change install type to RAM
 - [x] Implement the base classes in `common/`
 - [x] Implement the derived classes for the Pico
 - [x] Implement pipes for data and control
 - [x] Get a minimal serial port forwader running
 - [x] Test the serial port forwarder
 - [x] Implement data vs. command mode and a few AT commands in `common`
 - [x] Implement a DELAY event (absolute time, number of bytes, flush FIFO)
 - [x] Implement a MNP scanner that can insert delays after a block is received
 - [x] Test with script
 - [x] Clean up Workspace
 - [ ] Rename `send()` to `relay()` to make it clearer what the function does?
 - [ ] UserInterface class to control LEDs and listen to buttons
 - [ ] Optional firmware to reset Flash memory? Or any other way to reset it?
 - [ ] MNP Filter that extracts Dock commands and data (takes care of negotiation, blocks, replies, checksums, resends)
 - [ ] Matrix, a filter that routes data between multiple sockets
 - [ ] Dock, a filter that understands and handles Newton Dock commands
 - [ ] Async class for all things that take more time than we have in a slice
    - [ ] Async log: logging via debugging serial port or to SD Card
    - [ ] Async SD Card data and directory reading
 - [ ] Fill in missing documentation
 - [ ] Pipe could be able to handle block data in addition streaming data
 - [ ] Verify that we actually run on a PiPico, and not a NewtCOM dongle

 ## Notes

 - In `CMakeLists.txt`, we set `pico_set_binary_type(newt_dongle no_flash)`. 
    Delete this line to permanetly flash devices.
 - Set HSKO to 29 on XIAO, and to 22 on PiPico)
 - Apply for a USB Vendor ID: https://github.com/raspberrypi/usb-pid
 - Change USB Port name: https://sourcevu.sysprogs.com/rp2040/picosdk/files/src/rp2_common/pico_stdio_usb/stdio_usb_descriptors.c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
 - `#if defined(PICO_RP2040) ...`

 ## Hardware

 The pack is built with 10.5mm long pin headers, giving a top-bottom distance
 of 9.1 to 9.5mm. The overall hight is 12.5mm without USB and 13.9mm with USB
 connector. 
 
 Tip of the plug to front edge of PCBs is 10.4mm. Length over all is 31mm and
 32.5mm including the USB port.

 Width is 17.8mm. 

 The original dongle is 21.4 to 24.7mm wide, 20mm tall, and 39.4mm long 
 with Interconnect and 32,4mm without.

## Staus Report

The dongle can pipe data from the serial port to the USB port and back reliably
at 115200. Various test were done with NCX and BasiliskII and Inspector. 

### Timing

All devices are handles in a loop. The Newton typically communicates at 
38'400bps, but also allows 57.6, 115.2, and even 230.4kbps. The main loop
must handle at least 4'000, and at a maximum 24'000 characters per second.

The RP2040 uart supports a 32 bytes rx and tx fifo buffer. To avoid overflow,
the FIFO must be handled 125 to 750 times a second, or every 8000 or 1300 
microseconds. In the current implementation, I measured a maximum of 13 
microseconds in the CDC endpoint and 15 usec in the entire wheel.

Note however that writing to stdout messes this up tremendously and makes
the dongle lose data.

Talking about lost data. Even with HSKI and HSKO implemented, we still run out
of sync on larger files and screen dumps. I need code that triggers this
error reliably and more code to insert delays into the data transfer. 

### The Chirp

At a few points in the documentation, it was mentioned that the Newton
sends out "chirps" to let devices know that they are connected. These
chirps are a frequency sent out on HSKO when for example Dock is started.
Maybe we can use this for something?

### Pipes

(move this chapter elsewhere)

This is a firmware for a microcontroller that connects an Apple Newton 
MessagePad (MP2x00, eMate300) to the modern outside world over USB-C.
Wifi and Bluetooth are planned, but not implemented yet.

This code sees devices like the serial port and USB es Endpoints. An endpoint
can send Events to another enpoint using Pipes. Pipes generally unidirectional.
Connecting two endpoints will usually require two pipelines, one in each 
direction.

Pipe::send() will pass Events from the sending Endpoint's output to the 
reciving Endpoint. The reciver will either handel the event and return OK, 
or reject the event, expecting the sender to send the same event again in a 
later cycle of the scheduler. These events may be buffered along the way,
but will always stay in order.

Endpoints can bypass buffers in the pipeline using Pipe::rush() and will
immediatly receive an reply to the event. This will change the order of
events.

Lastly, pipes can send events up the pipe using Pipe::rush_back(). This is 
currently used by a receiving andpoint to give the sender hints for serial
port handshaking when buffers run full.

Pipes can have additional functionality. They can buffer events, or split
events into two streams which is great for logging traffic. Pipes can filter
events and add new events. The MNP Throttle looks for specifc sequences and
adds delays in the line to give the receive time to recover.

More complex filters can combine and upstream and a downstream pipe. The Hayes
interpreter is such a device. It understands Hayes 'AT' commands and can
reroute data as needed.

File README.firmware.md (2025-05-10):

# Newton MessagePad MP2x00 and eMate 300 USB Dongle Firmware

Welcome to the firmware repository for the Newton MessagePad 2x00 and eMate 300 USB dongle! This project brings Apple's iconic 1995 handheld PDA into the modern era by enabling seamless data transfer between the Newton devices and modern computers via a USB-C connection.

More documentation on the [NewtCOM Dongle](hardware/README.md) currently under development.

## What Does This Firmware Do?

This firmware powers a hardware dongle that acts as a bridge between the Newton's serial port and a USB-C port. It allows you to:
- Transfer files, packages, and data between your Newton device and a modern computer.
- Use tools like NCX, BasiliskII, and Inspector to interact with your Newton.
- Emulate Newton's docking protocol for advanced data handling.

The firmware is designed to handle high-speed communication reliably, supporting baud rates of up to 230,400 bps.

## Features

- **Serial-to-USB Communication**: Pipes data between the Newton's serial port and the USB port.
- **Error Handling**: Implements mechanisms to handle data loss and synchronization issues.
- **Flexible Event System**: Uses a modular, event-driven architecture for handling data and commands.
- **Support for Multiple Baud Rates**: Works with 38,400, 57,600, 115,200, and 230,400 bps.
- **Extensible Design**: Includes support for filters, buffers, and switches to customize data handling.
- **Future-Proof**: Designed to support additional features like SD card storage and advanced Newton protocols.

## How It Works

The firmware is built around a **pipe-based architecture**:
- **Pipes**: Modular components that process and forward events (e.g., data, commands).
- **Events**: Compact 32-bit messages that represent actions or data to be processed.
- **Filters**: Specialized pipes that modify or analyze data streams (e.g., Hayes command handling, MNP throttling).
- **Devices**: Hardware interfaces like UART (serial port) and USB endpoints.

This architecture ensures flexibility, scalability, and maintainability, making it easy to add new features or adapt to different hardware configurations.

## Current Status

- **Working**: Reliable data transfer at 115,200 bps. Successfully tested with NCX, BasiliskII, and Inspector.
- **In Progress**: Addressing occasional synchronization issues during large file transfers.
- **Planned**: Adding support for advanced features like SD card storage, statistics, and Newton Docking Protocol emulation.

## Getting Started

1. **Hardware Requirements**:
   - Raspberry Pi Pico or compatible RP2040-based board.
   - USB-C connection to your computer.
   - Serial connection to your Newton device.

2. **Building the Firmware**:
   - Clone this repository.
   - Follow the instructions in the `CMakeLists.txt` file to build the firmware using the Pico SDK.

3. **Flashing the Firmware**:
   - Use the Raspberry Pi Pico's bootloader to flash the firmware onto the device.

4. **Connecting Your Newton**:
   - Plug the dongle into your Newton's serial port and your computer's USB port.
   - Use your favorite Newton tools to start transferring data!

## Contributing

Contributions are welcome! Whether it's fixing bugs, adding features, or improving documentation, feel free to open a pull request or issue.

## License

This project is licensed under the MIT License. See the `LICENSE` file for details.

---

Thank you for keeping the Newton alive! If you have any questions or need help, feel free to reach out.

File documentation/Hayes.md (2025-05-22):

# Hayes Command Set

This firmware supports the Hayes protocol ("AT commands") on both the Interconnect Port and the USB port.

To switch from **data mode** to **Hayes command mode**, follow these steps:
1. Do not send any characters for at least 1 second.
2. Type three `+` characters (`+++`) with no more than 1 second beteen them.
3. Do not send anything again for 1 second.

The device will then switch to Hayes command mode and reply with `OK⮐`.  
To return to **data mode**, type `ATO⮐`.

## Supported Commands

| Command | Description |
|---|---|
| `+++` | In data mode: enter Command Mode |
| `ATO` | Switch back to data mode |
| `ATI` | Display device information |

## Setting and reading Registers

| Command  | Description |
|---|---|
| `ATS12`  | escape code guard time (1/50th of a second) |
| `ATS300` | absolute MNP throttle delay in microseconds |
| `ATS301` | relative MNP throttle delay in characters |
| `AT&W` | write the current setting to Flash memory |

### SD Card debugging Commands

| Command | Description |
|---|---|
| `AT[DS` | EXPERIMENTAL: Disk Status (NOINIT, NODISK, PROTECT) |
| `AT[DI` | EXPERIMENTAL: Disk Initialize (NOINIT, NODISK, PROTECT) |
| `AT[GL` | EXPERIMENTAL: Get Label |
| `AT[SNs:i.v.r` | DON'T USE: set a serial number and hardware identifiers |

### Commands under evaluation

| Command | Description |
|---|---|
| `ATS2=n` | Set a new escape character (default is `+`) |
| `ATS12=n`  | Set escape code guard time (1/50th of a second)  |
| `ATZ` | Reset Hayes settings |
| `AT%En` | Set escape method (`+++`, DTR, etc.) |
| `AT&F0` | Restore factory settings |
| `AT&K0` | Set flow control (0=none, 1=hardware) |
| `AT&W0` | Save settings to NVRAM |

### Future Plans

#### MNP Control
- Implement package throttling.

#### Crossbar
- **Downstream**: Select between Serial and Modem.
- **Upstream**: Select between USB, SD, Wi-Fi, or Bluetooth.

#### Wi-Fi
- Add Wi-Fi settings (e.g., find networks, set SSID, and password).
- Support Serial and PPP communication over Wi-Fi.

#### Bluetooth
- Add Bluetooth settings (e.g., connect, set passcode).
- Support Serial communication over Bluetooth.

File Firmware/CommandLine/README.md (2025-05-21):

# Command Line based Newton Dongle test suite

```
// SPDX-License-Identifier: MIT
// Copyright (c) 2025 Matthias Melcher, robowerk.de
```

# This Target no longer compiles!

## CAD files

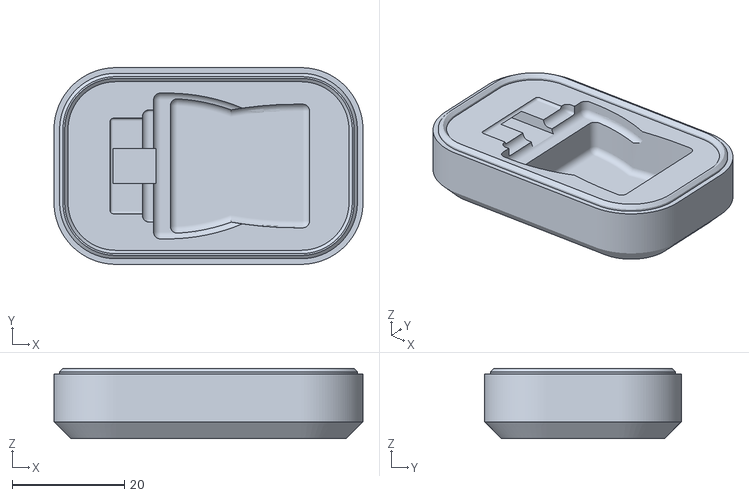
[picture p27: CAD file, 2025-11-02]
3d-parts/DongleCaseCase2.013-LowerCaseCaseBodyChamfered.stl
55.0 x 35.0 x 12.5

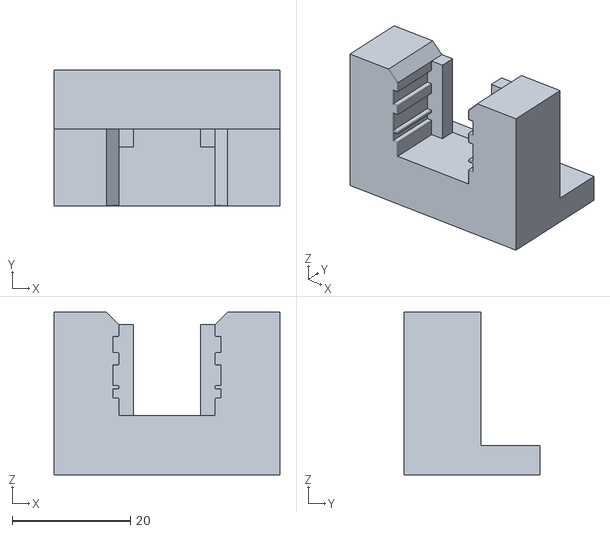
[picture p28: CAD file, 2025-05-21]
3d-parts/jigs/SolderJig1.002.stl
38.2 x 23.0 x 27.5

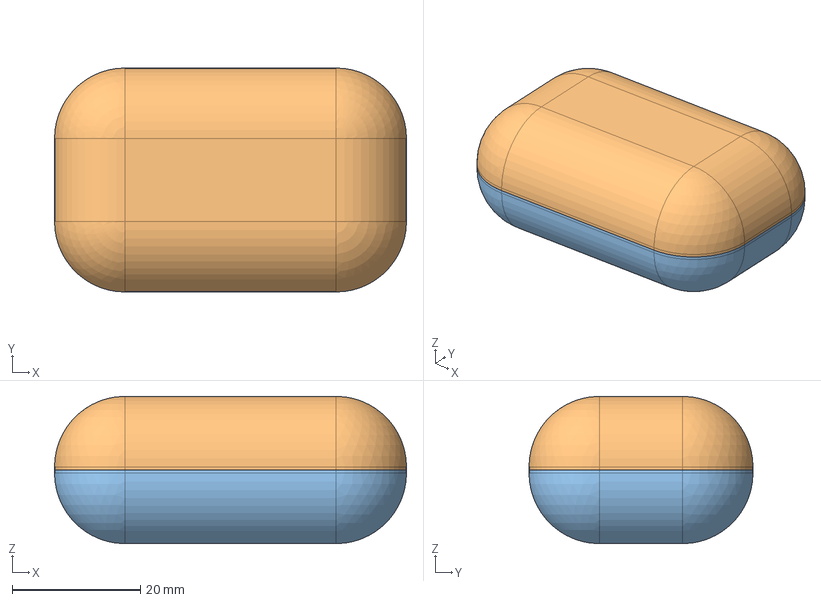
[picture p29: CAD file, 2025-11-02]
3d-parts/DongleCaseCase2.013.FCStd
55.0 x 35.0 x 23.0 mm

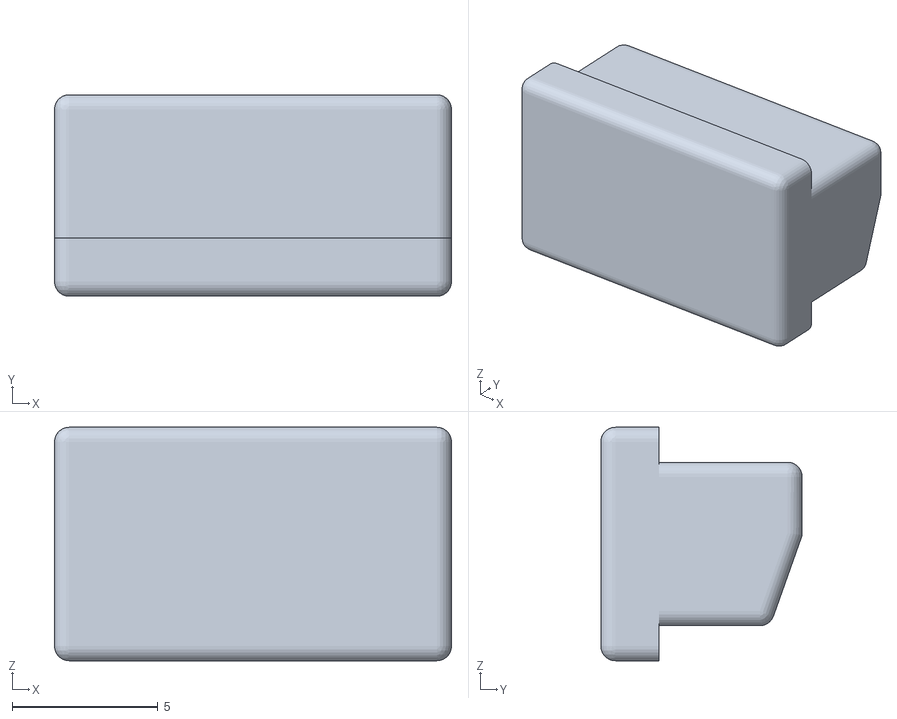
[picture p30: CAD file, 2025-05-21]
3d-parts/jigs/Last_Bender.Stamper.002.stl
13.6 x 6.90 x 8.00

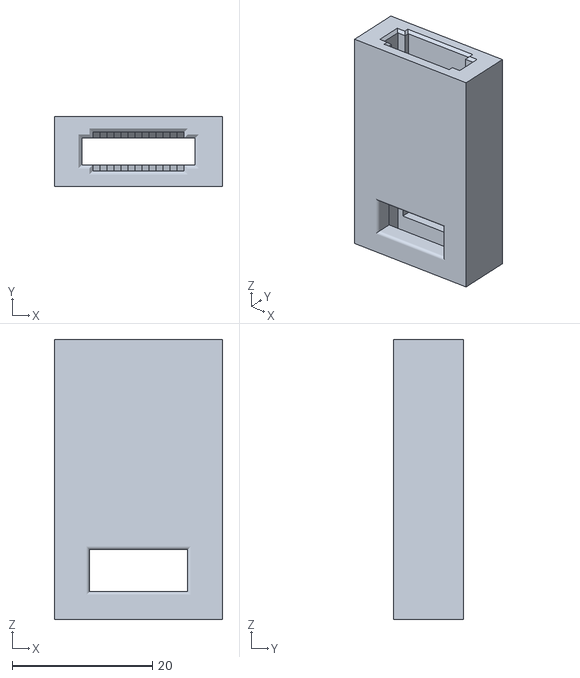
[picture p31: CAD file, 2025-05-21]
3d-parts/jigs/Last_Bender.Case.002.stl
24.0 x 10.0 x 40.0

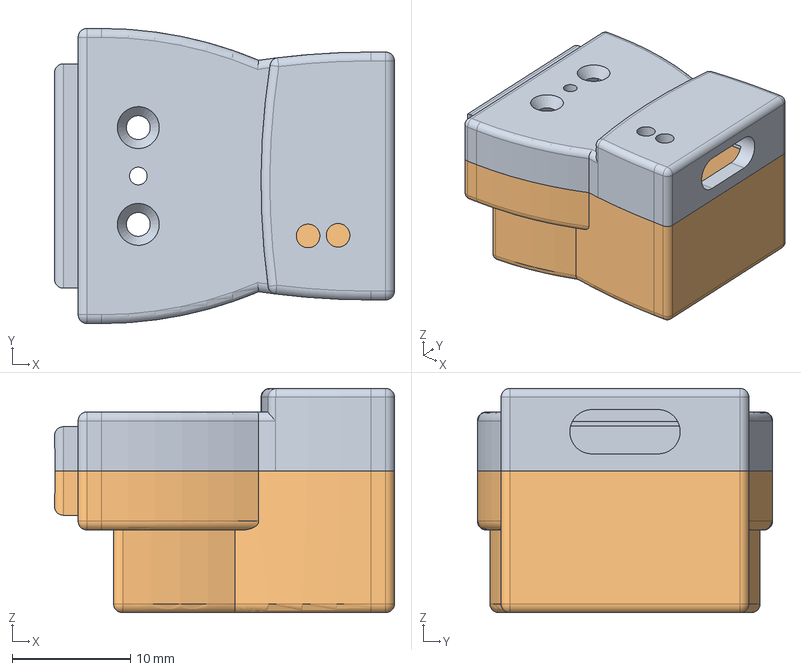
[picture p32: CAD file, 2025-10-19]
3d-parts/DongleCase5.015.FCStd
28.8 x 25.0 x 19.0 mm
Case_Top
Case_Bottom

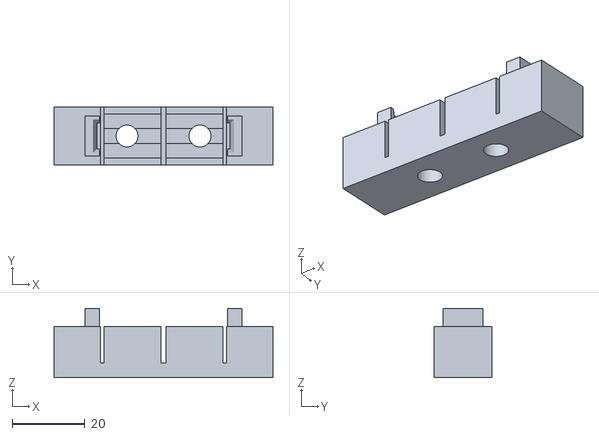
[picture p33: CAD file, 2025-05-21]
3d-parts/jigs/Cutter.002.stl
60.0 x 16.0 x 19.0

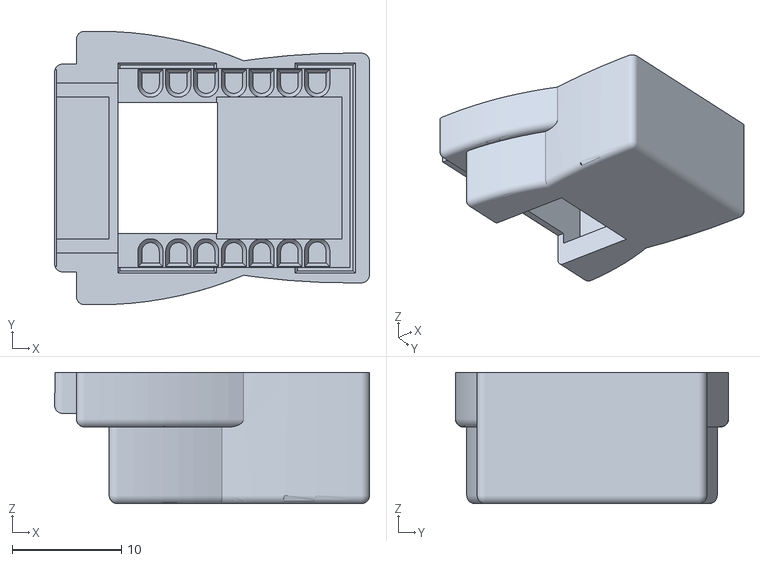
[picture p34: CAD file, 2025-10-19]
3d-parts/DongleCase5.015-Case_Bottom.stl
28.8 x 25.0 x 12.0

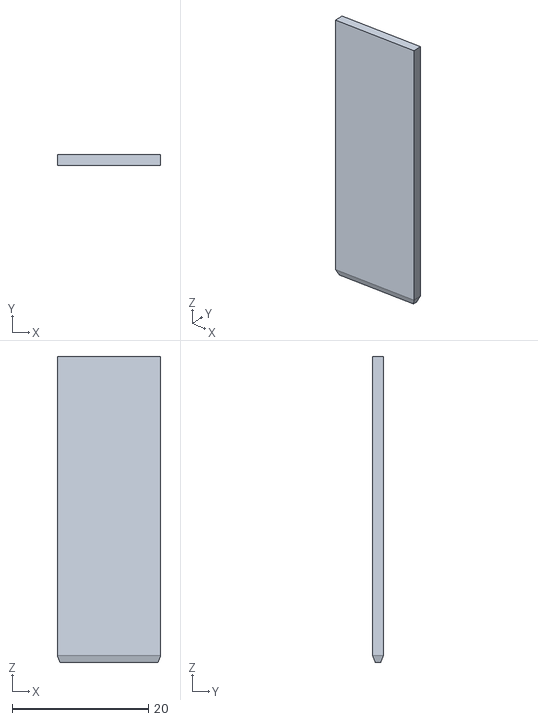
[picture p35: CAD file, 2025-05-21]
3d-parts/jigs/Last_Bender.Plunger.001.stl
15.2 x 1.60 x 45.0

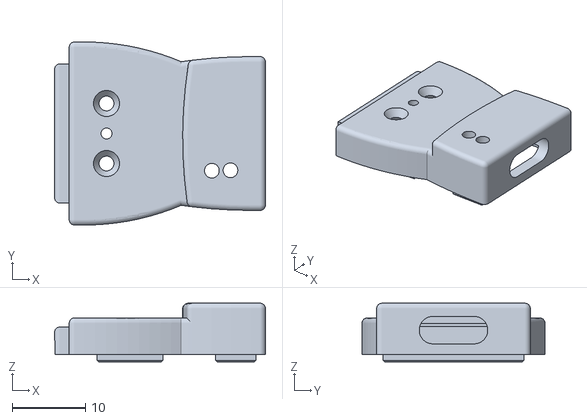
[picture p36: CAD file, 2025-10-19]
3d-parts/DongleCase5.015-Case_Top.stl
28.8 x 25.0 x 8.00

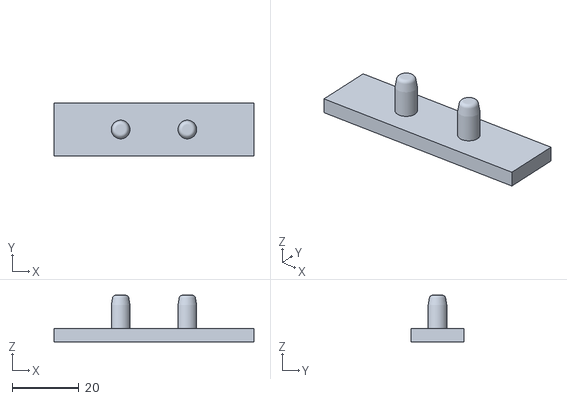
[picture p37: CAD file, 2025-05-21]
3d-parts/jigs/Bender.002-Ejector.stl
60.0 x 16.0 x 14.0

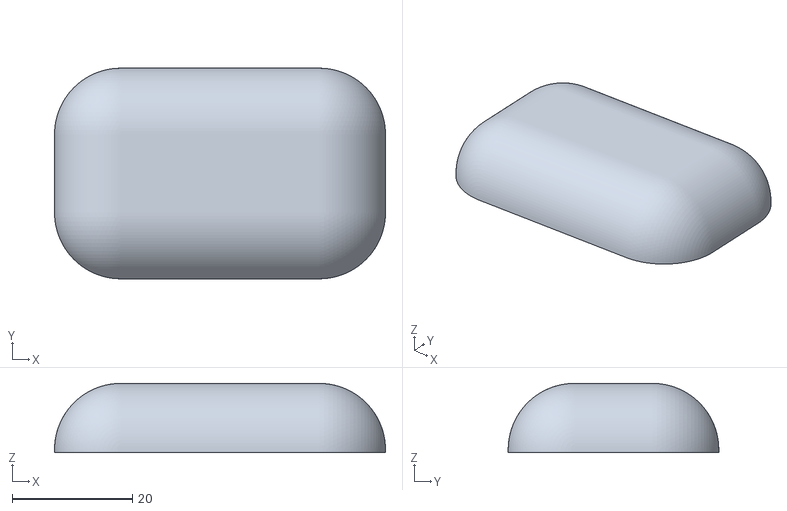
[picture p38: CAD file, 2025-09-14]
3d-parts/DongleCaseCase2.013-UpperCaseCaseBody026.stl
55.0 x 35.0 x 11.5

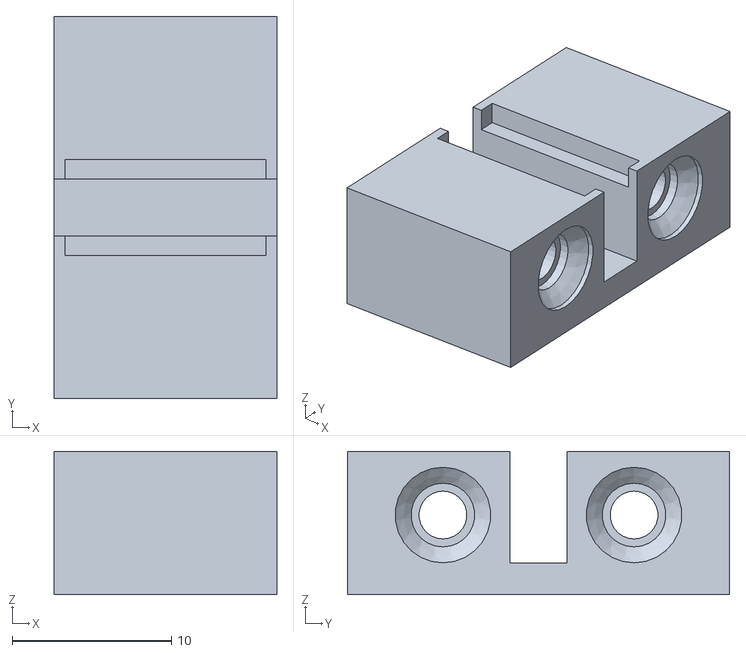
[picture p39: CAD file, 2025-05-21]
3d-parts/jigs/Detailer.001.stl
14.0 x 24.0 x 9.00

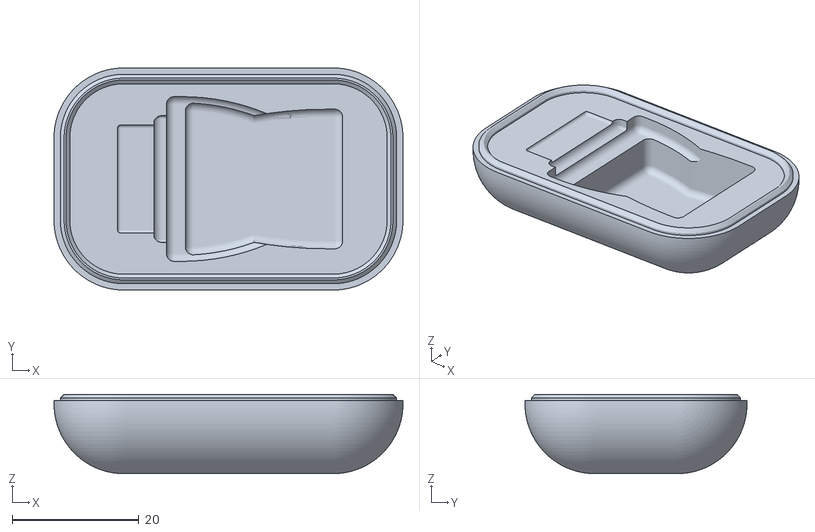
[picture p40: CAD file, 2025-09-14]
3d-parts/DongleCaseCase2.013-LowerCaseCaseBody026.stl
55.0 x 35.0 x 12.5

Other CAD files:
3d-parts/DongleCaseCase2.013-UpperCaseCaseBodyChamfered.stl
3d-parts/jigs/Detailer2.002.stl
3d-parts/DongleCase2.012-Bottom.stl
3d-parts/jigs/Bender.003-Bender.stl
3d-parts/DongleCase2.012-Top.stl

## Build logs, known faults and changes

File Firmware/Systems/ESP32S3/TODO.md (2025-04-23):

# My TODO List for ESP32

## Initial steps:

 - [ ] List the SP devices that we want to support (Internal, Debugging, Dongle board)
   - Jake: ESP32-S3-Mini-1u (CDC/MSC)
   - Debug: ESP32-S3-Wroom-1
   - Dongle: Ordered a XIAO ESP32-C6 for testing (no MSC! See S3, C3 for CDC/MSC, but builtin antenna)
   - [ ] Check if we must create different folders for different CPUs and/or modules
 - [ ] Make it easy to switch between devices
 - [ ] Check if the current Workspace compiles and debugs on our current hardware
 - [ ] Change install type to RAM (ESP?)
 - [ ] Implement the base classes in `common/` for USB to Serial (also in PiPico)
 - [ ] Implement the derived classes for the ESP
 - [ ] Get a minimal serial port forwader running
 - [ ] Test the serial port forwarder
 - [ ] Implement data vs. command mode and a few AT commands in `common` (also in PiPico)
 - [ ] Test with script
 - [ ] Implement statistics (also in PiPico)
 - [ ] Clean up Workspace!

## Basic hardware support:

 - [ ] Get SD Card support going
 - [ ] add modem endpoint basics
 - [ ] add BLE endpoint basics
 - [ ] add Wifi endpoint basics

## Notes

 - ESP-C6 USB port is hardwired for JTAG/CDC, but not for MSC!

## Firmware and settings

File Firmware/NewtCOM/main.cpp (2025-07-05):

/*
  MIT License

  Copyright (c) 2025 Matthias Melcher, robowerk.de

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
  THE SOFTWARE IS PROVIDED "AS IS", WITHOUT WARRANTY OF ANY KIND, EXPRESS OR
  IMPLIED, INCLUDING BUT NOT LIMITED TO THE WARRANTIES OF MERCHANTABILITY,
  FITNESS FOR A PARTICULAR PURPOSE AND NONINFRINGEMENT. IN NO EVENT SHALL THE
  AUTHORS OR COPYRIGHT HOLDERS BE LIABLE FOR ANY CLAIM, DAMAGES OR OTHER
  LIABILITY, WHETHER IN AN ACTION OF CONTRACT, TORT OR OTHERWISE, ARISING FROM,
  OUT OF OR IN CONNECTION WITH THE SOFTWARE OR THE USE OR OTHER DEALINGS IN THE
  SOFTWARE.
*/

/*
 Use this project to create ROM Images for the NewtCOM Dongle.

 This is Version 0.6a. It has the following features:
  - Dock protocol emulation 
    - Connect to emulated NCU via Dock protocol
    - Browse files on SD Card, download , and install
 The Version 0.5. It has the following features:
  - Connects the UART to the CDC endpoint.
  - Hayes filter on both ends to allow Modem commands
  - Throttle MNP Packages from CDC to UART
  - Save settings in Flash RAM
  - Status Display to show the current status of the system.

Hardware Version 4.0

                __[   ]__  USB-C
     PORT_SEL -[ 26      ]- +5V
       SD_SEL -[ 27      ]- GND
         HSKI -[ 28      ]- +3.3V
         HSKO -[ 29    3 ]- SD_MOSI
         GPIO -[ 6     4 ]- SD_MISO
  DOCK_ATTACH -[ 7     2 ]- SD_SCK
          TX0 -[_0__()_1_]- RX0
                  BATT+


 DOCK_ATTACH must be pulled high. To wake the Newton up, pull low for 1ms (max. 2ms).
 If held low for more than 10ms, Newton will see it as a Docking Event.
 It should be held low until the dock is removed.
 The implementation for NewtCOM could mirror the DTR on the USB port. It could 
 also reflect if a Dock connection to the SD Card is active.

 PORT_SEL can be read. If the internal serial port is selected, we should ignore
 all traffic on Serial 0.

 GPIO can be defined as an input or output. For NewtCOM it is useless without a
 Newton application. If we have a Newton app, we could use iit to get us into
 Hayes command mode, even if all settings are messed up.

 */

#include "main.h"

#include "PicoAsyncLog.h"
#include "PicoUARTEndpoint.h"
#include "PicoCDCEndpoint.h"
#include "PicoScheduler.h"
#include "PicoSystemTask.h"

#include "common/Endpoints/Dock.h"
#include "common/Endpoints/StdioLog.h"
#include "common/Filters/DTRSwitch.h"
#include "common/Filters/HayesFilter.h"
#include "common/Filters/MNPFilter.h"
#include "common/Pipes/BufferedPipe.h"
#include "common/Pipes/MNPThrottle.h"
#include "common/Pipes/Tee.h"

#include <pico/stdlib.h>

#include <stdio.h>


using namespace nd;

// Saves setting into Flash Memory.
PicoUserSettings user_settings;

// Log to debugging probe on uart1.
PicoAsyncLog Log(0);

// Distributes times slices to all tasks.
PicoScheduler scheduler;

// One task to manage the overall system.
PicoSystemTask system_task(scheduler);

// Task that updates the status display.
PicoStatusDisplay app_status(scheduler);

// Endpoints for data exchange.
PicoUARTEndpoint uart_endpoint { scheduler };
PicoCDCEndpoint cdc_endpoint { scheduler, 0 };
PicoSDCardEndpoint sdcard_endpoint { scheduler };
Dock dock_endpoint(scheduler);

// Filters and loggers.
HayesFilter uart_hayes(scheduler, 0);
HayesFilter cdc_hayes(scheduler, 1);
MNPFilter mnp_filter(scheduler);
DTRSwitch dtr_switch;

// Pipes to connect everything.
MNPThrottle mnp_throttle(scheduler);
BufferedPipe buffer_to_cdc(scheduler);
BufferedPipe buffer_to_uart(scheduler);


// -- Everything is already allocated. Now link the endpoints and run the scheduler.
int main(int argc, char *argv[])
{
    system_task.reset_hardware(); 

    sdcard_endpoint.early_init(); // Initialize the GPIOs for the SD card
    app_status.early_init(); // Initialize the status display

    stdio_uart_init_full(uart1, 115200, 8, 9);
    
    // user_settings.mess_up_flash();
    user_settings.read();
    scheduler.signal_all( Event {Event::Type::SIGNAL, Event::Subtype::USER_SETTINGS_CHANGED} );

    // -- Connect the Endpoints inside the dongle with pipes.
    // UART ---------------> UART_Hayes --------------------> DTRSwitch ---> CDC Hayes ---> buffer ---> CDC
    // UART <--- buffer <--- UART_Hayes <--- MNPThrottle <--- DTRSwitch <--- CDC Hayes <--------------- CDC
    //                                                           ↑↓
    //                                                           MNP
    //                                                           ↑↓
    //                                                          Dock    
    //                                                           ↑↓
    //                                                         SDCard    

    // Connect the UART to the Dock or the CDC, depending on the CDC DTR pin.
    /**/  uart_endpoint >> uart_hayes.downstream;
    /**/    uart_hayes.upstream >> dtr_switch;
    /**/      dtr_switch.dock >> mnp_filter.newt;
    /**/        mnp_filter.newt >> dock_endpoint;
    /**/      dtr_switch.cdc >> cdc_hayes.upstream;
    /**/        cdc_hayes.downstream >> buffer_to_cdc >> cdc_endpoint;
    // Connect the USB CDC and the Dock back to the UART.
    /**/  dock_endpoint >> mnp_filter.dock;
    /**/    mnp_filter.dock >> dtr_switch.dock;
    /**/  cdc_endpoint >> cdc_hayes.downstream;
    /**/    cdc_hayes.upstream >> dtr_switch.cdc;
    /**/      dtr_switch >> mnp_throttle >> uart_hayes.upstream;
    /**/        uart_hayes.downstream >> buffer_to_uart >> uart_endpoint;

    // -- Give both serial ports access to the SD Card (currently for debugging only)
    uart_hayes.link(&sdcard_endpoint);
    cdc_hayes.link(&sdcard_endpoint);

    // -- The scheduler will call all instances of classes that are derived from Task.
    scheduler.init();

    // -- Now we can start the scheduler. It will call all spokes in a loop.
    scheduler.run();

    // -- Never reached.
    return 0;
} 

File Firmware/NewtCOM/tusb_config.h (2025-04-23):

/*
 * The MIT License (MIT)
 *
 * Copyright (c) 2019 Ha Thach (tinyusb.org)
 *
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
 */

 #ifndef _TUSB_CONFIG_H_
 #define _TUSB_CONFIG_H_
 
 #ifdef __cplusplus
  extern "C" {
 #endif
 
 //--------------------------------------------------------------------+
 // Board Specific Configuration
 //--------------------------------------------------------------------+
 
 // RHPort number used for device can be defined by board.mk, default to port 0
 #ifndef BOARD_TUD_RHPORT
 #define BOARD_TUD_RHPORT      0
 #endif
 
 // RHPort max operational speed can defined by board.mk
 #ifndef BOARD_TUD_MAX_SPEED
 #define BOARD_TUD_MAX_SPEED   OPT_MODE_DEFAULT_SPEED
 #endif
 
 //--------------------------------------------------------------------
 // Common Configuration
 //--------------------------------------------------------------------
 
 // defined by compiler flags for flexibility
 #ifndef CFG_TUSB_MCU
 #error CFG_TUSB_MCU must be defined
 #endif
 
 #ifndef CFG_TUSB_OS
 #define CFG_TUSB_OS           OPT_OS_NONE
 #endif
 
 #ifndef CFG_TUSB_DEBUG
 #define CFG_TUSB_DEBUG        0
 #endif
 
 // Enable Device stack
 #define CFG_TUD_ENABLED       1
 
 // Default is max speed that hardware controller could support with on-chip PHY
 #define CFG_TUD_MAX_SPEED     BOARD_TUD_MAX_SPEED
 
 /* USB DMA on some MCUs can only access a specific SRAM region with restriction on alignment.
  * Tinyusb use follows macros to declare transferring memory so that they can be put
  * into those specific section.
  * e.g
  * - CFG_TUSB_MEM SECTION : __attribute__ (( section(".usb_ram") ))
  * - CFG_TUSB_MEM_ALIGN   : __attribute__ ((aligned(4)))
  */
 #ifndef CFG_TUSB_MEM_SECTION
 #define CFG_TUSB_MEM_SECTION
 #endif
 
 #ifndef CFG_TUSB_MEM_ALIGN
 #define CFG_TUSB_MEM_ALIGN    __attribute__ ((aligned(4)))
 #endif
 
 //--------------------------------------------------------------------
 // DEVICE CONFIGURATION
 //--------------------------------------------------------------------
 
 #ifndef CFG_TUD_ENDPOINT0_SIZE
 #define CFG_TUD_ENDPOINT0_SIZE    64
 #endif
 
 //------------- CLASS -------------//
 #define CFG_TUD_CDC              1
 #define CFG_TUD_MSC              0 // Matt: set this to 1 to allow the dongle to appear as a USB mass storage device
 #define CFG_TUD_HID              0
 #define CFG_TUD_MIDI             0
 #define CFG_TUD_VENDOR           0
 
 // CDC FIFO size of TX and RX
 #define CFG_TUD_CDC_RX_BUFSIZE   (TUD_OPT_HIGH_SPEED ? 512 : 64)
 #define CFG_TUD_CDC_TX_BUFSIZE   (TUD_OPT_HIGH_SPEED ? 512 : 64)
 
 // CDC Endpoint transfer buffer size, more is faster
 #define CFG_TUD_CDC_EP_BUFSIZE   (TUD_OPT_HIGH_SPEED ? 512 : 64)
 
 // MSC Buffer size of Device Mass storage
 #define CFG_TUD_MSC_EP_BUFSIZE   512
 
 #ifdef __cplusplus
  }
 #endif
 
 #endif /* _TUSB_CONFIG_H_ */

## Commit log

2025-04-23 Initial commit based on example projects
    [partitions.csv]
2025-04-23 Add different folders for different MCUs
    [partitions.csv]
2025-04-24 Add Pi Pico USB/CDC support
2025-04-30 Base implementation of Wheel and Pipes
2025-05-01 Ready to switch from Test to PiPico
2025-05-01 Pico code cleaned and working well.
2025-05-01 CDC can now request a bitrate change.
    UART can handle a bitrate change request.
2025-05-04 First fully working firmware.
    Implements UART, USB-CDC,
    Hayes, MNP Throtteling, and delays
2025-05-10 Docs: First stage to build a connector.
    [Connector_Prebend_Jig.stl]
2025-05-11 connector docs
2025-05-19 Adding MNP throttle delay registers
2025-05-21 Add missing 3D STLs
    [Bender.002-Ejector.stl, Bender.003-Bender.stl, Cutter.002.stl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]
2025-05-21 Add naother jig for soldering
    [DongleCase2.012-Bottom.stl, SolderJig1.002.stl]
2025-05-28 Dock protocol advances, NSOF module buggy
    [Dock.h]
2025-06-04 Adding cross platform FLTK App that will mirror dongle features on the desktop.
    [partitions.csv]
2025-06-11 Added status LED, added basic directory reading and changing directory.
2025-06-12 Adding package loading via dock. Fixed bug when there are multiple DLE ina single page.
    [Dock.h]
2025-06-13 Added automatic switch between CDC and Dock.
2025-06-21 Better us of docking pin.
2025-07-05 Change displayed USB CDC device name
2025-09-14 Add outer case.
    [DongleCaseCase2.013-LowerCaseCaseBody026.stl, DongleCaseCase2.013-UpperCaseCaseBody026.stl]
2025-10-19 Adding case for V5 PCB
    [DongleCase5.002-Case_Bottom.stl, DongleCase5.002-Case_Top.stl, DongleCase5.002.FCStd]
2025-10-19 Improved case
    [DongleCase5.002-Case_Bottom.stl, DongleCase5.002-Case_Top.stl, DongleCase5.002.FCStd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]
2025-10-31 Added FreeCAD file for the the carrying case
    [DongleCaseCase2.013.FCStd]
2025-11-02 Add optional magnet slots and a chamfered outside style
    * Add slots for 6x2mm magnets
    * Add a chamfered outside for printers that struggle with the fillet
    * Add STL files of the case with both options enabled
    Both options are toggled via booleans in a VarSet.
    [DongleCaseCase2.013-LowerCaseCaseBodyChamfered.stl, DongleCaseCase2.013-UpperCaseCaseBodyChamfered.stl, DongleCaseCase2.013.FCStd]
2026-10-18 Job 0.1: Add host unit tests
    Host build of selected common/ files with ASan and UBSan, a minimal test framework, and first NSOF encoder tests against data captured from NCU.
2026-10-18 Job 1.2: Calculate the MNP CRC over unsigned bytes
    A signed char >= 0x80 indexed outside of the CRC table. No change on RP2040, where char is unsigned. The new test replays a captured Newton/NCU session; our frames match NCU byte for byte.
2026-10-18 Job 1.4: Keep UARTEndpoint::bitrate() in sync
    PicoUARTEndpoint::set_bitrate() did not call the base class, so delays in characters used 38400 baud.
2026-10-18 Job 1.5: Fix bounds checks in SD card and SPI lookup
    sd_get_by_num() and spi_get_by_num() accepted an index one past the end; spi_get_by_num() compared against the SD card count.
2026-10-18 Job 2.1: Reset all MNP state on disconnect, new LR, and DTR change
    set_disconnected() now clears both pipes, releases all frames except the
    one the receiver is handling, and tells the Dock. A pending LT from the
    previous session no longer blocks the next one. DTRSwitch forwards a real
    DTR change to the MNP filter, which aborts the frame being received and
    disconnects.
2026-10-18 Job 2.2: Drop duplicate and out of sequence LT frames from the Newton
    Only an LT with the next sequence number is forwarded to the Dock. For
    any other LT, the last accepted frame is acknowledged again and the data
    is dropped, so a lost LA no longer delivers the payload twice.
2026-10-18 Job 2.3: Resend unacknowledged LT frames and disconnect after 4 tries
    Scheduler::now_us() adds up the cycle times. An LT that is not
    acknowledged within 3 seconds after its last CRC byte is sent again.
    After 4 resends, the filter disconnects, tells the Dock, and sends LD
    with reason 4 (retransmission limit reached).
2026-10-18 Job 2.4: Bound received MNP data and resync on SYN and DLE STX
    Received frames may carry at most 256 data bytes. Repeated SYNs before
    DLE STX are accepted, DLE STX inside a frame starts a new frame, and the
    header (including its size byte) is un-escaped in one place. An invalid
    escape in the header now really aborts the frame.
2026-10-18 Job 3.1: Reject oversized Dock payloads with dres, resync on 'n' and new frames
    A received command payload larger than 32 KB is answered with dres
    kDockErrBadCommandLength, so the Newton shows an error, and the parser
    looks for the next "newtdock". A failed "newtdock" match re-checks the
    byte for 'n', and a new MNP frame ends a half received command header.
    The Dock error codes in Dock.h are enabled.
    Dock is now part of the host tests, with stubs for app_status and the
    SD card.
2026-10-18 Fix use after scope of the desktop name in send_cmd_path()
    The Frame on the stack was destroyed after the String it referenced.
    The String is now allocated like all other strings in this function.
2026-10-18 Job 3.3: Build Dock commands in buffers owned by the queue
    All commands are built by queue_command_(), which appends the header,
    payload and padding to a new buffer that the queue frees after sending.
    Commands queued back to back no longer overwrite each other. The bytes
    on the wire are unchanged, verified by golden tests of every command.
2026-10-18 Document the PiPico (RAM, test rig) and NewtCOM (flash, dongle) builds
    PiPico is the breadboard test rig: Raspberry Pi Pico pin map, runs from
    RAM, loaded with a debug probe, error logging on. NewtCOM is the dongle:
    XIAO RP2040 pin map, runs from flash, logging off, and is the source of
    all release images.
2026-10-18 Job 4.2: Start the MNP pause when the UART line is idle
    TXFE is set while the last byte of a block is still in the shift
    register, so the pause overlapped that byte. BUSY clears only after the
    stop bit has gone out.
2026-10-18 Job 4.3: Write to the UART only when the TX FIFO is empty
    HSKO is checked before each byte, but up to 32 bytes in the FIFO still
    went out after the Newton dropped CTS. Now at most two bytes do.
2026-10-18 Job 4.4: Send HIGH_WATER upstream and recover it after a mode change
    BufferedPipe put ON/OFF into the data field instead of the subtype,
    space() returned the used count, and the event went downstream. Now a
    filling buffer_to_cdc drops HSKI so the Newton pauses. An OFF after a
    RESET is ignored, and a DTR change resets the UART handshake, so a full
    buffer on the old side can't block the Newton.
2026-10-18 Job 4.5: Keep the host bitrate and restore the Dock bitrate on DTR changes
    Most host apps set the bitrate before they raise DTR, and the switch
    dropped SET_BITRATE while DTR was low. DTRSwitch now remembers the host
    bitrate and applies it when DTR rises, sets kUART_BaudRate (38400) for
    Dock mode when DTR drops, and keeps a rejected bitrate pending until it
    can go out ahead of the next byte.
2026-10-18 Job 4.6: Receive UART data by interrupt and count receive errors (ATI3)
    The task read one byte per cycle and uart_getc() dropped the error
    flags, so a slow cycle could overflow the 32 byte RX FIFO unnoticed. An
    interrupt now moves the data into a 1024 byte ring buffer and counts
    overrun, framing and break errors and buffer overflows. ATI3 shows the
    counters.
2026-10-18 Job 4.7: Track the longest scheduler cycle and show it in ATI3
    ATI3 shows the longest scheduler cycle since the last ATI3. Measured:
    1.6 ms in direct connect, 162 ms in standalone mode with SD access.
    The 1024 byte RX ring holds 267 ms at 38400, so SD access stays in
    Dock::send(). CLAUDE.md lists the limits for later checks.
2026-10-18 Job 5.1: Build our sources with -Wall -Wextra and fix all warnings
    Log.logf() gets the printf format attribute, which found 27 wrong calls.
    Formats, enum switches, unused parameters and variables, signed
    compares and the HayesFilter init order are fixed. Two real bugs: ATSn
    without = or ? fell through into AT&W and wrote the settings to flash,
    and DESPermute() read an uninitialized value (without effect on the
    result). Both firmware builds and the host tests now use -Wall -Wextra
    for our own sources.
2026-10-18 Job 5.6: Add host tests that play complete docking sessions
    The test plays the Newton through MNPFilter and Dock: it sends Dock
    commands in LT frames, decodes and acknowledges the dongle's frames,
    and checks a full session up to a package install, and a cancelled
    install. The captured frames and the frame builder move into
    Tests/captured.h and Tests/mnp_util.h.
